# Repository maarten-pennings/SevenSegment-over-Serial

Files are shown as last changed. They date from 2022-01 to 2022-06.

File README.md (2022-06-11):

# Seven Segment over Serial (SSoS)
A device consisting of 7-segment display units, controllable via a serial link (with Arduino sketch and LEGO enclosure).

See a videos of the device in action.

video (https://youtu.be/2fTZVQPiG7E) video (https://www.youtube.com/watch?v=muLhuRukZes)



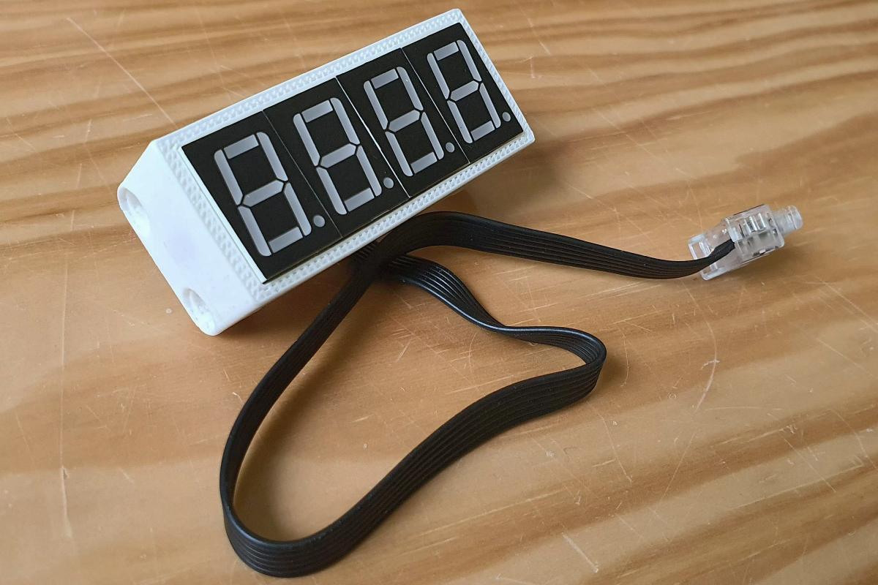
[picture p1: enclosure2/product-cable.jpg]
SSoS for LEGO


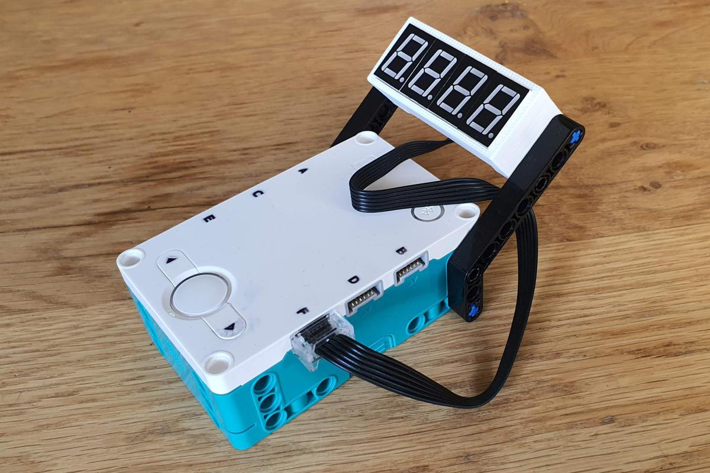
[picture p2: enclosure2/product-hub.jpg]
Connected to the hub


## Introduction
I stumbled on this module [Seven Segment for micro:bit](http://www.monkmakes.com/mb_7_seg.html).
I immediately thought that such a thing would be a nice external display for the new LEGO Mindstorms Robot Inventor - it
does not have a display - at least not one that can display bigger numbers. But I want it smaller to better fit LEGO.

Later I found that [sparkfun](https://learn.sparkfun.com/tutorials/using-the-serial-7-segment-display/all) has something similar.
This board is also a bit too wide to my liking, and _retired_.

## Font
There is a [python script](font) to generate font tables. 
I designed two fonts, one _LookAlike7s_ with characters that are as close as possible to the real thing.
The second font _Unique7s_ maps each character to a unique pattern on the 7-segment display.

## Electronics
Design of the [electronics](electronics): the power architecture, display control, wiring (used pins), schematics, and finally PCB with IDC socket.
My project on EasyEDA is [public](https://oshwlab.com/maartenpennings/ssos).

## ISR model
Modeling the [interrupt service routine (ISR)](isr). The ISR needs to support brightness control and blinking.
The model is made in Python, but in the end, the ISR is the central part of the ATmega firmware, driving the 7-segments.

## Firmware
The [firmware](firmware) for the Arduino Nano, the controller on the SSoS board.
First some proof of concept sketches (using SFRs for ports, timer, ISR), finally the [end-product](firmware/SSoS).

## User manual
There is an extensive [user manual](manual) with examples (as implemented by the [firmware](firmware/SSoS)).

## LEGO enclosure 
I 3D-printed an [enclosure](enclosure) so that I can use SSoS with LEGO Mindstorms.

## LEGO demo
See the [LEGO code](legocode) for some examples of how to use the SSoS device with LEGO.

## Generation 2: Seven Segment over Serial Small
The (LEGO) enclosure we made is 4×8 LEGO units (studs). But LEGO Technic components usually have an _odd_ length.
So I set out to miniaturize making a Seven Segment over Serial _Small_ (SSoSS).
Target is 3×7. To achieve this, I made a single PCB, combining both the "Nano" and the 7-segment units.

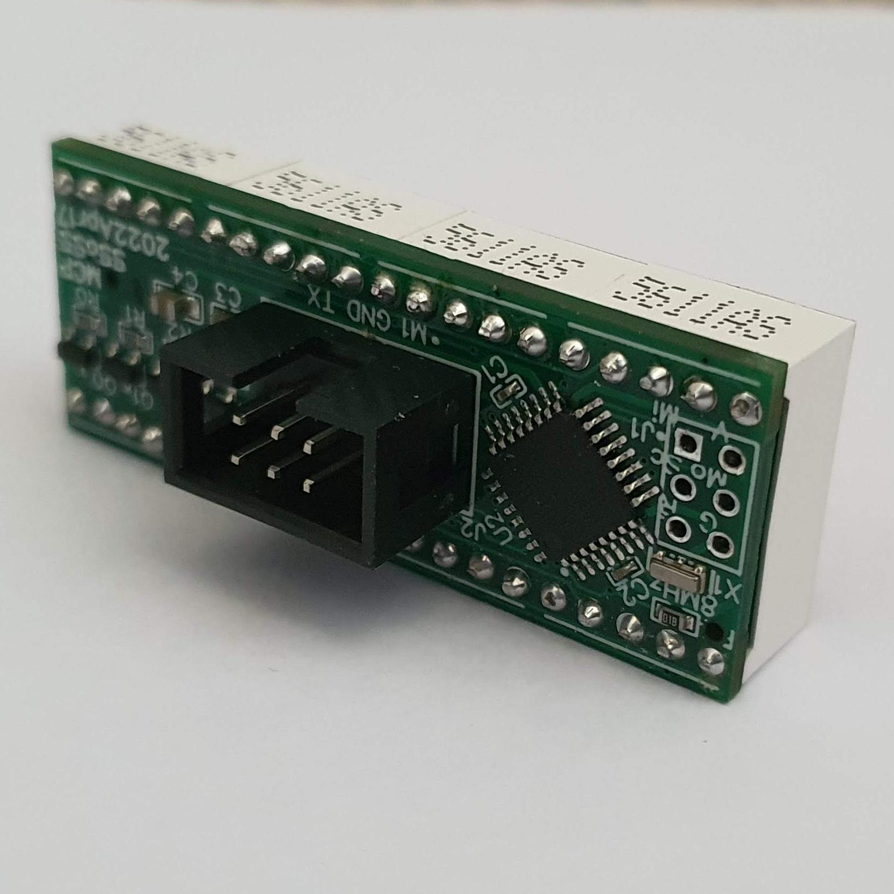
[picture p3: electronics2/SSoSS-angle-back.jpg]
pcb2


Section [electronics2](electronics2) shows the schematics and the unexpected firmware flashing problems.

Section [enclosure2](enclosure2) shows the new enclosure, 3D printed via [JLCPCB](https://jlcpcb.com/DMP).

(end)

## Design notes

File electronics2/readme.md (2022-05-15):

# Electronics - version 2 (small)

Seven-Segment over Serial: a device consisting of four 7-segment display units, 
controllable via a serial link, to be usable as display for LEGO Mindstorms Robot Inventor or Spike Prime.

This page is about the _second_ iteration of the electronics.

The first iteration, depicted below, needed a miniaturization. 

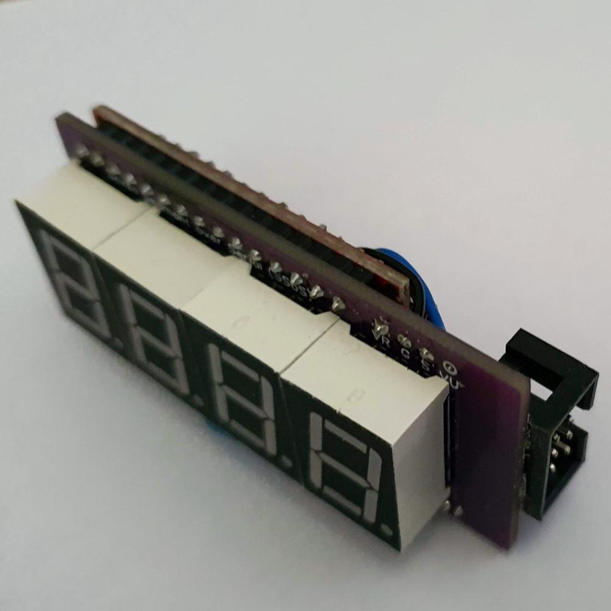
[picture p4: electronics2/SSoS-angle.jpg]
SSoS for LEGO


Miniaturization is achieved by using the SMT service of [JLCPCB](https://jlcpcb.com/DMP).
They sponsored this project.

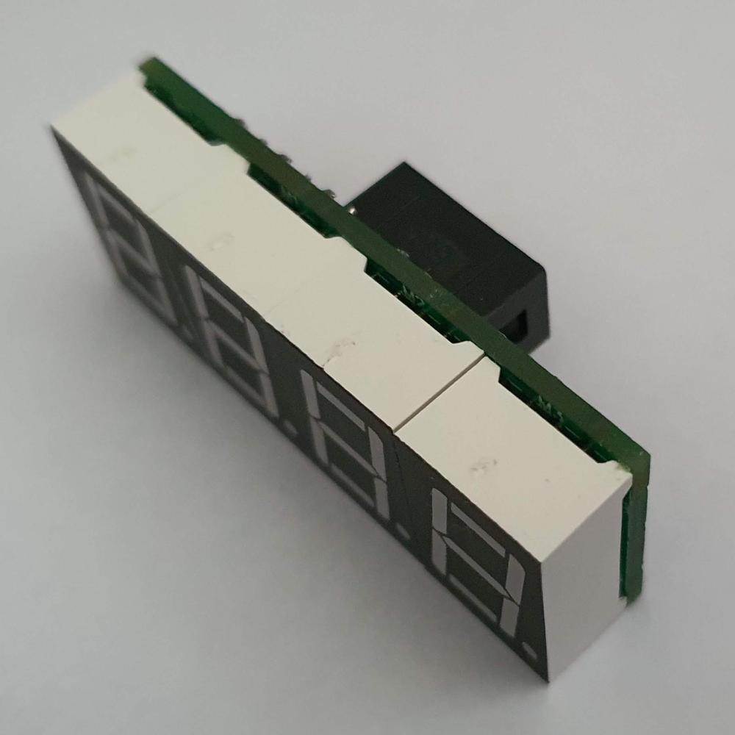
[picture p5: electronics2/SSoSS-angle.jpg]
SSoSS for LEGO


SSoSS for LEGO (backside)

## Introduction

In this miniaturization step I tried to make the design smaller by integrating two boards: "SSoS" and "Nano". 
The "SSoS" board is the board from the [first iteration](../electronics), 
and the "Nano" is a standard Arduino Nano.
The integrated board is nicknamed SSoSS: Seven-Segment over Serial Small.

For firmware, fonts, enclosure, user manual, LEGO code, see parent [page](..).

This article is about switching to SMT components.

## How to get a PCB with components mounted by JLCPCB?

I make all my PCB designs with [EasyEDA](https://easyeda.com/).
Once the design is ready, I let EasyEDA export a Gerber, and I send that to [JLCPCB](https://jlcpcb.com/DMP) to get it manufactured.
There is a third company in the mix, [LCSC](https://lcsc.com/); this is a component supplier.

### EasyEDA - select components

Design the schematics as usual.
For each component you add to the schematics you have to make a choice
 - JLCPCB can't mount it because JLCPCB can only mount on one side of the board and this component needs to be on the other side.
 - JLCPCB can't mount it because its supplier, LCSC, doesn't have the component on stock.
 - You tell JLCPCB not to mount it because it is only needed for testing, or you have plenty stock yourself, or its is cheaper.
 - ... You want it mounted.

In the latter case be sure to select a component from LCSC, because that is the supplier of JLCPCB.
There are three classes of components
 - JLCPCB can not deliver it (not in LCSC catalog or the LCSC stock is depleted).
 - The component is a so-called _Extended Part_. 
   This means that JLCPCB has it, but it is not in the parts feeder by default.
   An operator needs to change the feeder on the pick-and-place machine, 
   you have to pay ~$3 per extended component class (plus the normal per-component cost).
 - It is a so-called _Basic Part_. 
   This means that JLCPCB has it in the feeders of the pick-and-place machines.
   You only pay the per-component cost.

There are two ways to find a component: 
you can do that in EasyEDA designer or on JLCPCB website.

### Finding a component in EasyEDA

Finding a component in the EasyEDA design tool.
 - Open the `Library` tool in the designer.
 - Enter a search term, e.g. `220 0805` for a 220 ohm resistor in size 0805.
 - Search in `Class` LCSC.
 - Sort on `JLCPCB Part Class` so that we can check if there is a _Basic Part_ (they are cheaper after all).
 - Click the wanted component and check _Stock_ at the bottom of the screen (example below: 182000 pieces).
 - An important number is the _LCSC Part#_, also at the bottom line.
   See the example in below screenshot, finding component `C17557`.
 
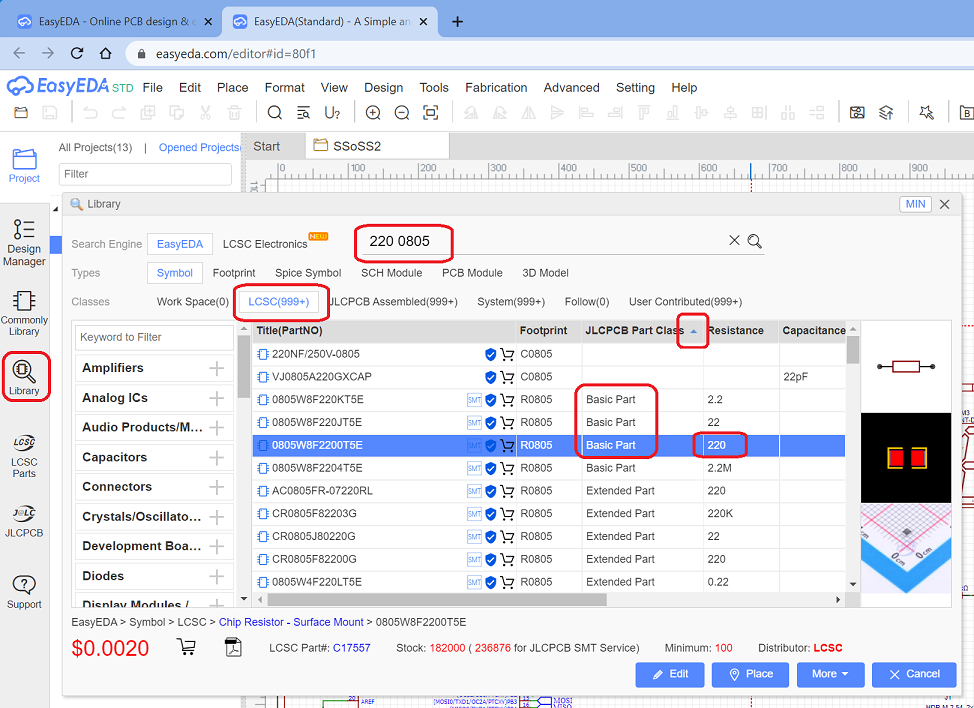
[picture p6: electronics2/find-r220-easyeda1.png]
EasyEDA find component
   

### Finding a component in JLCPCB

Finding a component in the EasyEDA design tool works OK.
But somehow, I find it easier to search for parts on the JLCPCB website.

 - In the main page select `Resources` then `SMT Parts Library`.
 
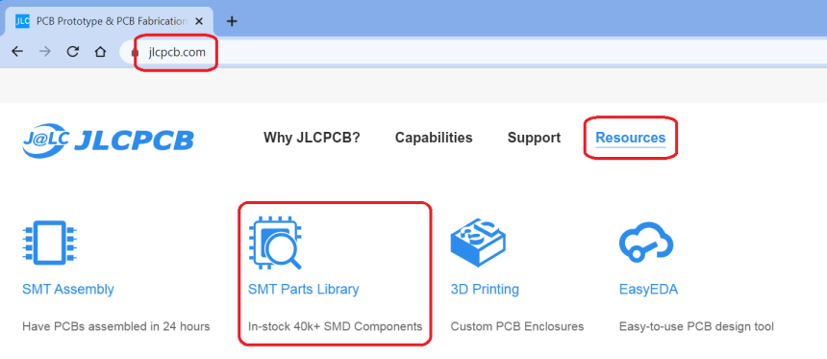
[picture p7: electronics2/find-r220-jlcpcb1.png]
JLCPCB find page
   
   
 - You can search by category (resistors, transistors, diodes), and/or using filters, or simple keyword search.
   For example if you search for `220Ω 0805` (ALT-235 gives the Ω in windows) and place a check mark for _Basic Parts_
   we find the same component as before.
   
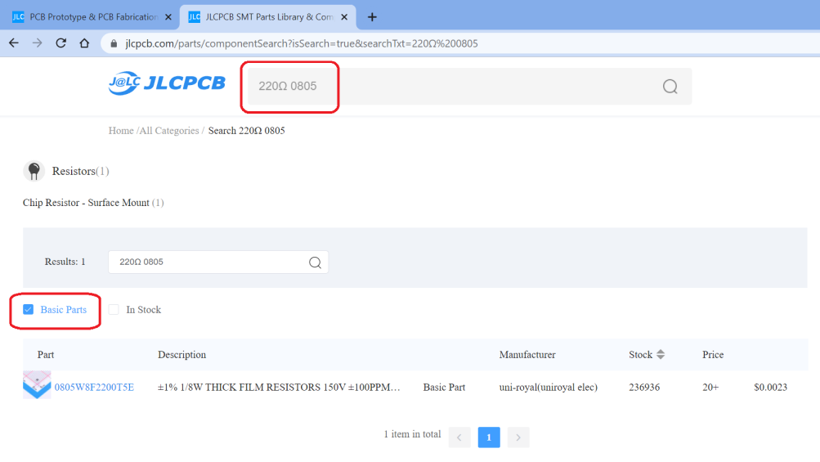
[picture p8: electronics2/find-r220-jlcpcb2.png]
JLCPCB find search
   
   
 - Click the component for to fold open its details
 
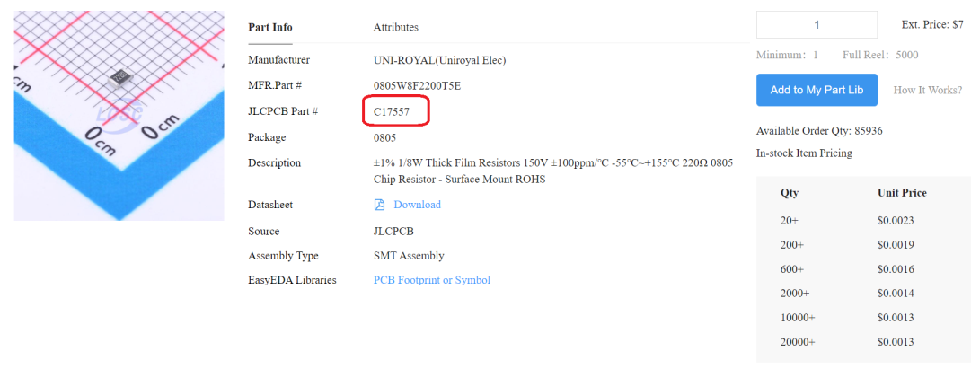
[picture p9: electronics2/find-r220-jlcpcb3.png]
JLCPCB find page
   
   
   Note that we have the same part number as when searching via EasyEDA.
   
 - Just enter that number in the Library search box of Easy EDA.
 
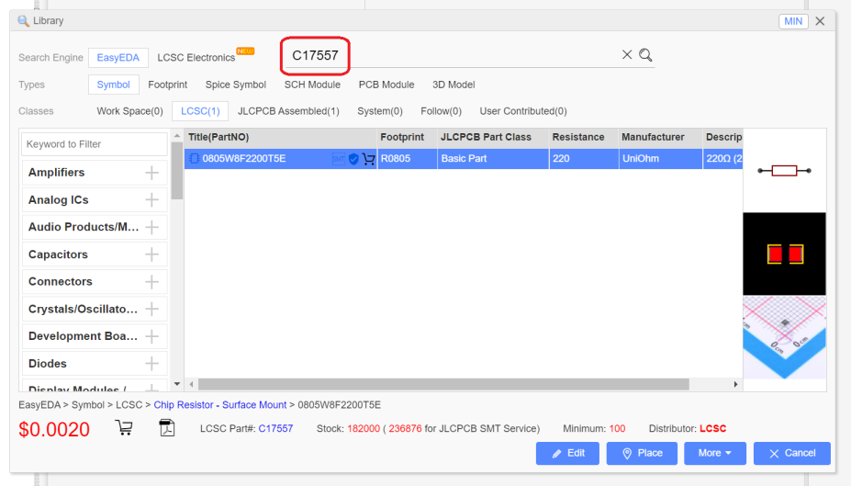
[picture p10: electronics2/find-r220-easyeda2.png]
EasyEDA find component
   

### EasyEDA - design PCB

After picking all SMD components, this is the resulting [schematic](Schematic_SSoSS.pdf).
You can't see it from the schematics (but you can see it in the EasyEDA designer), 
but all SMD components can be sourced from LCSC.

Once the schematics is drawn with the JLCPCB supported components, proceed to the PCB layout stage as usual.
No special attention here, other then to draw the components you want mounted all on the same side.

In my case, this is the resulting PCB, [front](front-3D.png) and [back](back-3D.png) view.
The back side will not be mounted by JLCPCB, so I took big 0805 components that I will mount myself.

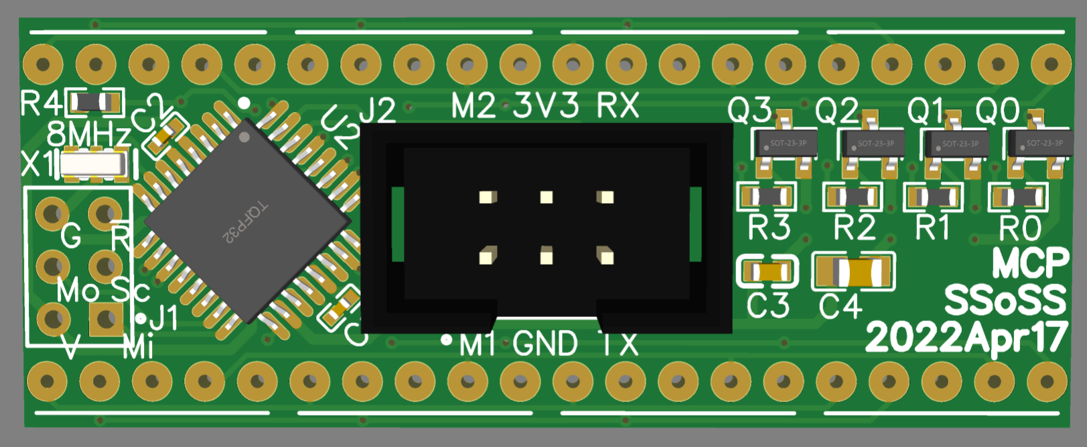
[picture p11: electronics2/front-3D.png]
front


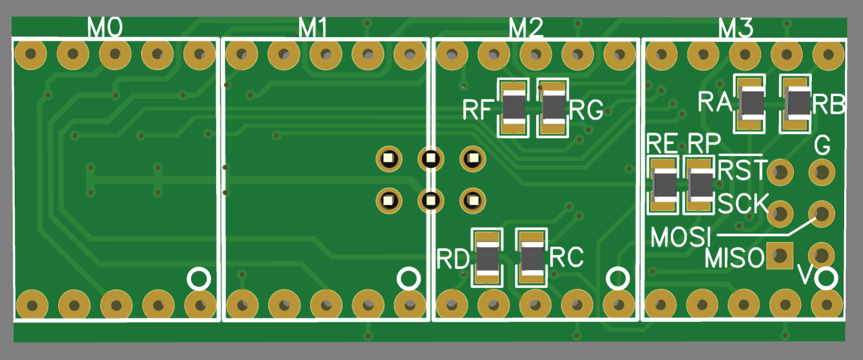
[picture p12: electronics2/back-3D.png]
back


An extra step is needed when exporting the project. In addition to the _Gerber_ file, 
JLCPCB needs a _bill of material_ (BOM) and _pick-and-place_ instructions.
You find the other two exports also in the `File` menu, above and below the Gerber exporter.

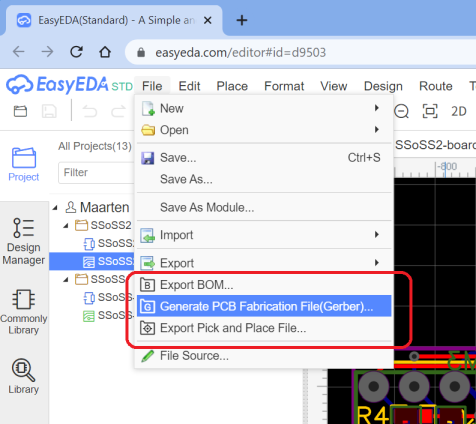
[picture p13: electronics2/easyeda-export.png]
export


For my project, all exported files are in the [order2](order2) directory.

### JLCPCB - import

We visit the [JLCPCB](https://jlcpcb.com/DMP) website to prepare our order.

 - Go to the PCB quote form.

 - Drag in the Gerber file we just exported. As usual we get a preview.
   We leave all parameters to standard. 
   Cost are very low: $2 for the special offer (5 small PCBs), plus nearly $4 for lowest shipping.

 - The first step is to enable component mounting at the bottom of the form.

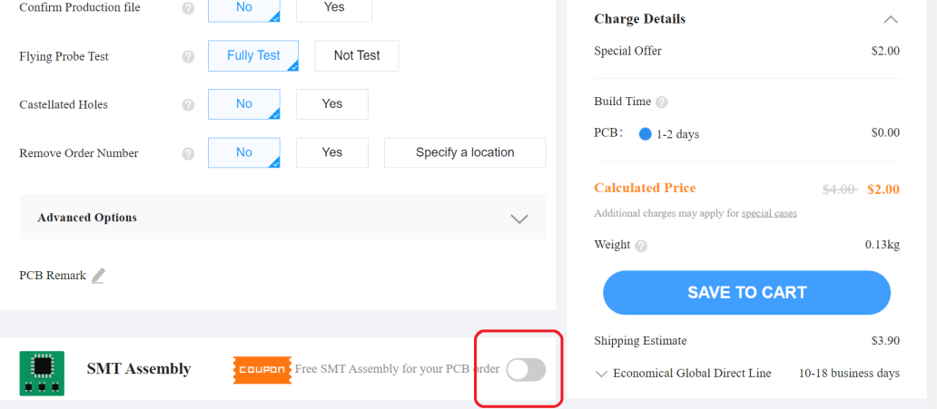
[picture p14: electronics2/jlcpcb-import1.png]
enable component mounting
   

 - The pricing changes. You now have to pay $8 general setup cost and $1.50 to make a stencil
   (a metal sheet with holes matching the component pads, this is used to apply the soldering paste at the correct spots).
   So total cost is now $2+$8+$1.50 or $11.50 plus shipping (still $4).

 - The quote form also expands: we have to chose which side will be populated with components, 
   and how many of the PCBs we want to be assembled. 
   Bit strange: we can only chose all 5 or just 2, but 2 is fine for me.

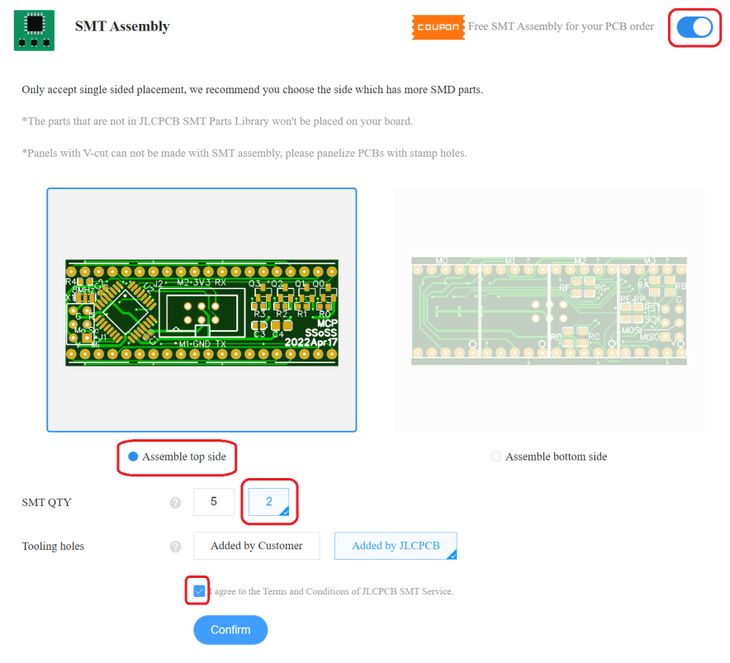
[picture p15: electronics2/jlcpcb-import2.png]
side and quantity
   

 - Once that is confirmed, we get a dialog, where we need to upload the _BOM file_ 
   and the _pick-and-place file_ we exported earlier. 
   Also you need to fill out the kind of project your are making, I selected `Electronics and Hobbies - DIY`.

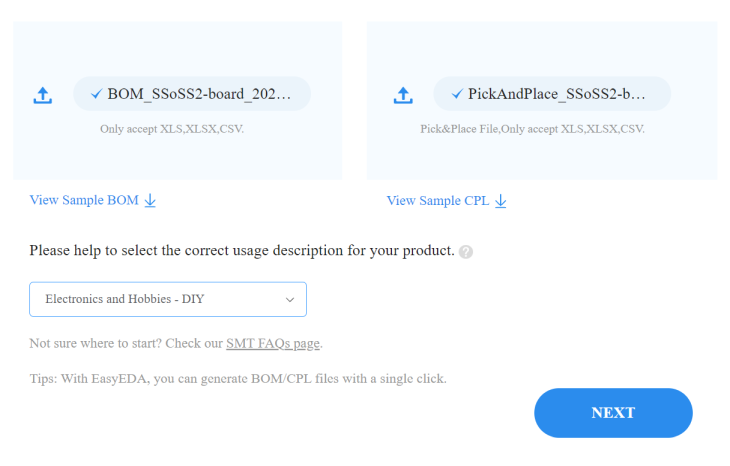
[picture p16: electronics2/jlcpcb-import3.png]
BOM and pick-and-place
   
 
 - Once the BOM and pick-and-place files are uploaded, we get a new form for part selection.
   Here we can see if there are problems with components (you selected one whose stock ran out - yes I had that!).
   More importantly, you can deselect components. For example, I do not want J1 and J2 to be mounted.
   I was surprised to see them enabled, because they are not SMT components, 
   but apparently JLCPCB has an optional hand mounting post processing step - nice!

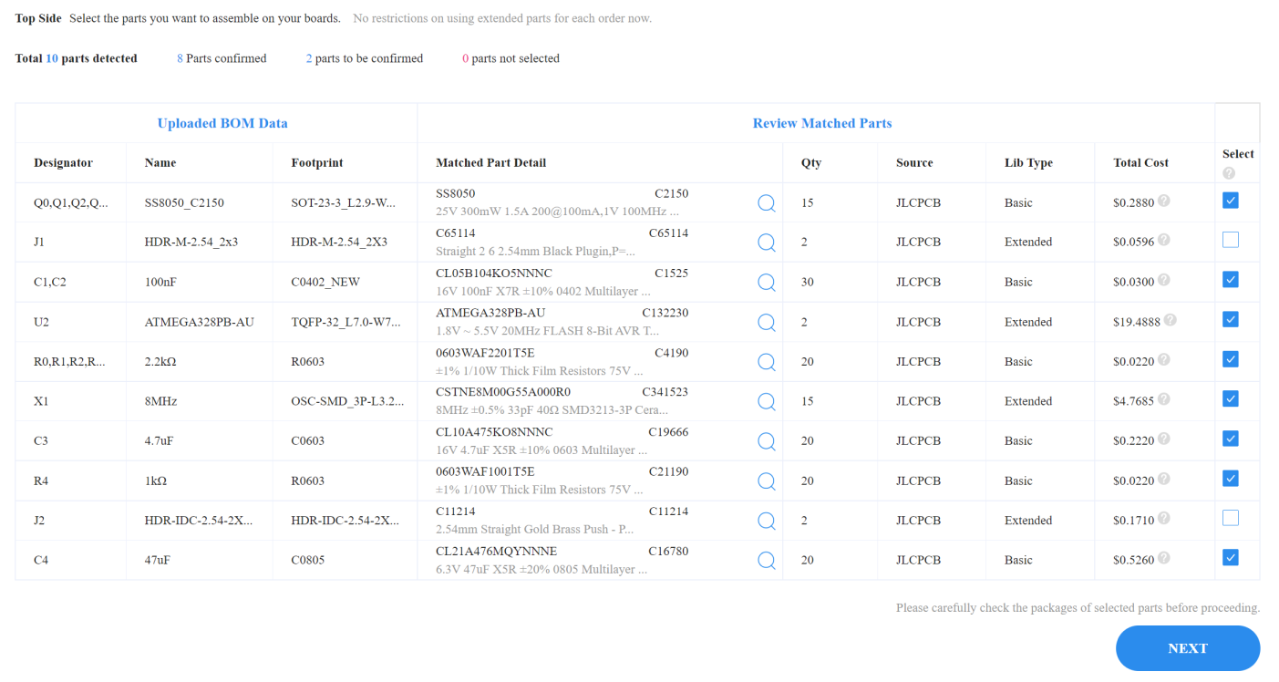
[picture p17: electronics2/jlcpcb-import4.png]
component deselect
   

   The Qty column confused me at first. It does _not_ show actual quantity, 
   but what "rank" your order is in (e.g. 1-19, 20-199, 200-599, 600-2999), because that determines the price.
   When you need low quantities (as I do) you are in the first rank. 
   That rank is a bit special: the price is fixed irrespective of quantity; 
   if you fold the line item open it reads e.g. `*For qty≤20, charges a fixed fee of €0.0203`.

   If you select an extended component, JLCPCB is required to change the feeders on the pick-and-place machines,
   which requires an additional labor fee, $3 per Extended Component type.

 - After clicking next, we are back at the main form.
 
   We see which components are placed (basically a copy of the previous  list), but also
   which components are not. In my case that is the two deselected headers and the components
   on the back side. A nice cross-check.
   
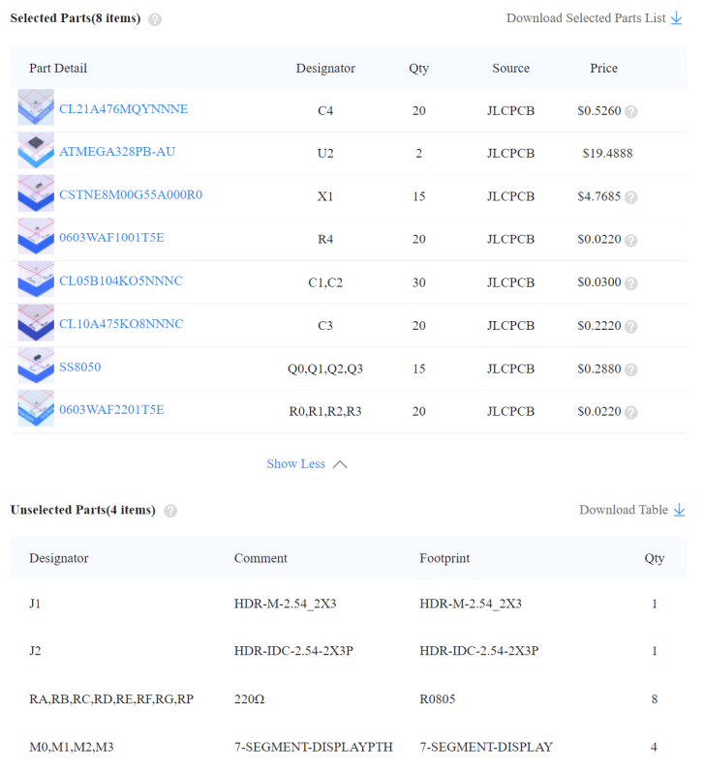
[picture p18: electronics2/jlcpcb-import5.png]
   
   
   Note that passives (resistors, capacitors) are typically very low priced 
   (although for these small quantities we are in lowest rank and pay the relatively high fixed price).
   The ATmega328 is unbelievably high priced. An Arduino Nano board with that ATmega328 goes for $2 on AliExpress.
   I guess I pay for the semiconductors shortage (April 2022).
   
   Also the oscillator is expensive. On top of that, the ATMEGA and oscillator are extended components so
   we need to pay an extra $3 for both.
   
 - Pricing has gone up: we have to pay for all components, we have to pay for changing the feeders 
   (2 extended components so $6 in total), and we have to pay for the solder 
   (JLCPCB states $0.0017 per solder joint but that would be nearly 400 joints).

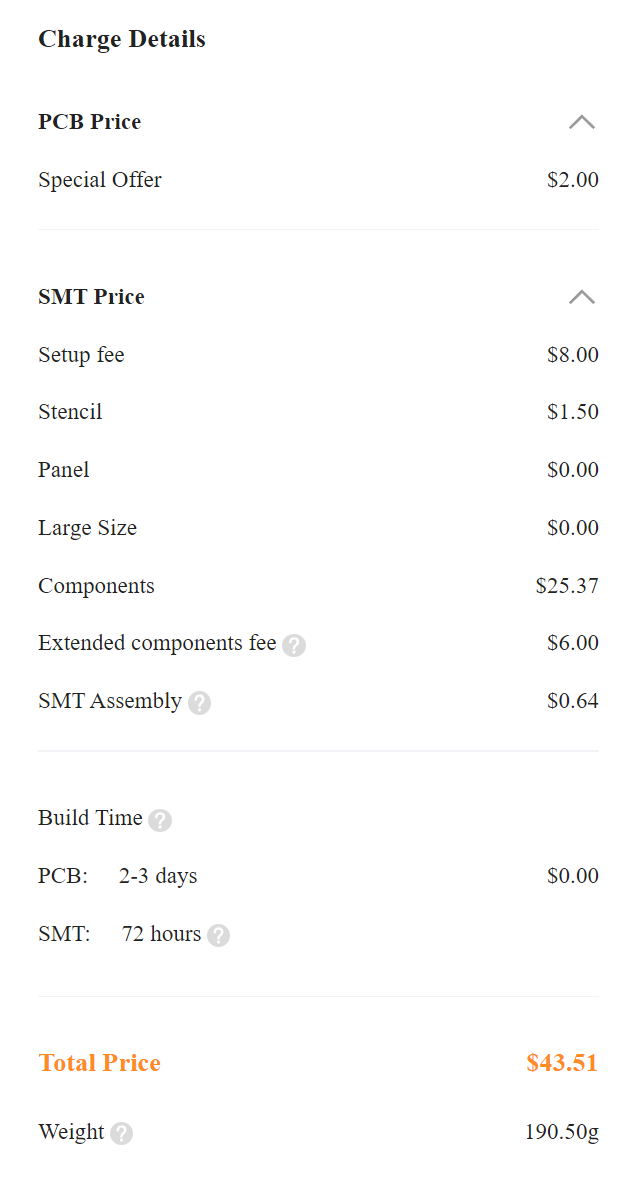
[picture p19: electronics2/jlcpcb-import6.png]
   
   
 - When I put this in my cart and paid, there was an unpleasant surprise.
   Suddenly I had to pay $12 tax. That had never happened before.
   And shipping increased to $8. Is that the extra weight?
   Feels a bit excessive. 
   
   I also stumbled on another problem: I had multiple gift cards (vouchers) but could only hand in one.

## Considerations and doubts on the tech side

Considerations before producing the board:
 - I used the ATmega328, not the ATM168 from SSoS, LCSC doesn't have the 168.
 - The ATmega328 on LCSC is very expensive ($10), so I only make two boards.
 - I'm a digital (software) guy, so I have doubts in the analogue domain
   - Do I have the correct oscillator (I need 8MHz for ATmega328 at 3V3) - correct capacitance?
   - Are the transistors correct?
   - There is no cap on the RESET# pin.
   - No ground poor.
 - I will solder J2 (IDC connector) myself, and J1 (ICSP) will not be mounted.
 - I will solder RA..RP myself (JLCPCB can only do one side), they are 0805.
 - I did make my own 3D model of the [IDC connector](IDC3dModel).

Considerations after producing the board:
 - One LED on the PCB might have been nice for testing bring-up.
 - A pad for PORTB0 would have helped in clock testing (see CKOUT fuse bit).
 - The ATmega328PB that I took is not nicely supported by Arduino. It works, but an ATmega328P would have been easier.

## Flashing

The board is back, from 2022-04-17 to 2022-04-23 for production and mounting (5 days) to 2022-05-04.
In total 18 days for manufacturing and shipping. 

There was one thing to caught me by surprise: the board had two holes I did not put there,
see the red encircled areas. I guess those are put by JLCPCB to have anchor points 
for the solder paste stencil.

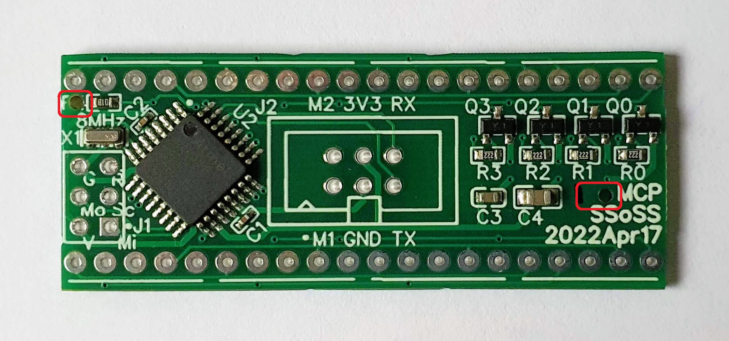
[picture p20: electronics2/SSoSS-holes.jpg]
SSoSS

 
The [flashing](flashing) took two days of trial and error, reason was I have the ATmega328PB, not standard ATmega328P.
This means fiddling with fuses, avrdude, and fixing a bug in the driver (hardcoded 16MHz clock).

## Assembly

Once the firmware was correctly working and flashed, and I could proceed with final assembly.
The components "brace" each other, so once assembled, there is little opportunity for changes.

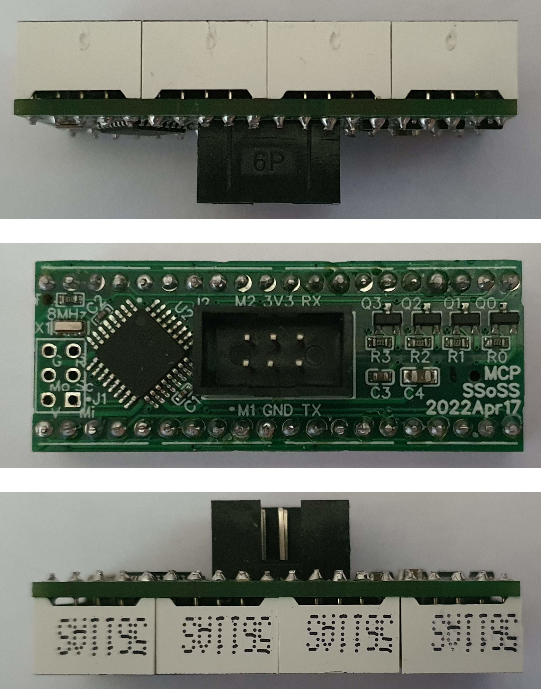
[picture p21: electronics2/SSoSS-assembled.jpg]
SSoSS assembled


## Enclosure

What is left is to make a new [LEGO enclosure](../enclosure2) for this smaller PCB.

(end)

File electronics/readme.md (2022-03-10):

# Electronics

Seven-Segment over Serial (SSoS) module: a device consisting of four 7-segment display units, 
controllable via a serial link, to be usable as display for LEGO Mindstorms Robot Inventor or Spike Prime.

This section is about the electronics of the SSoS board, 
design made with [EasyEDA](https://easyeda.com/) and manufactured by [JLCPCB](https://jlcpcb.com/DMP).

For firmware, fonts, enclosure, user manual, LEGO code, see parent [page](..).

This article was awarded a $50 voucher from [JLCPCB](https://jlcpcb.com/DMP).

## Arduino Nano power architecture

The heart of SSoS module is an Arduino Nano. 
We need to power it from a LEGO hub port, which is 3V3.
Is that possible? 

The diagram below is a high level view of the 
[schematics](https://www.arduino.cc/en/uploads/Main/ArduinoNano30Schematic.pdf) 
of a Nano, focusing on power.

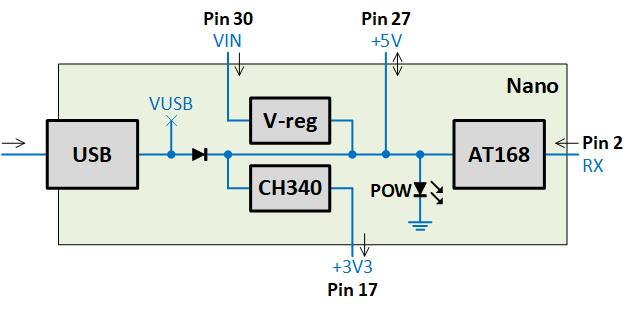
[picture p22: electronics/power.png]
Arduino Nano power architecture


A Nano can be powered via
 - the `USB` connector;
 - 6 to 20V _unregulated_ external power supply (pin 30, `VIN`) - it is regulated internally (by V-reg); 
 - 5V _regulated_ external power supply (pin 27, `+5V`).

Note that
 - the `+3V3` (pin 17) is a low-current output supplied by the CH340;
 - the `+5V` (pin 27) can be used as output, provided the Nano is powered via `USB` or `VIN`;
 - `VUSB` is not pinned out;
 - the "power" LED is connected to the internal 5V rail;
 - a diode protects a USB host in case the Nano is inadvertently connected via `USB` and `VIN`/`+5V`;
 - according to the datasheet the operating voltage is 2.7V-5.5V for Atmel ATmega48/88/168.
 - this means that we can use pin 27 `+5V` also as input, provided we attach a _regulated_ power in the range 2.7V-5.5V.

**Conclusion**
We power the board by connecting pin 27 (`+5V`) to the external host (LEGO hub).
This is fine as long as the external host a "standard" regulated voltage (e.g. 3V3 or 5V). 
It also means that the logic pins, e.g. the incoming `RX` will have the host level.

## Display control

How does the Nano control the four seven-segment units?

According to the ATmega48/88/168 datasheet:
 - each I/O port can **source** more than the test conditions (20mA at VCC = 5V, **10mA** at VCC = 3V)
 - the sum of all IOH, for ports C0 - C5, D0- D4, ADC7, RESET should not exceed 150mA.
 - the sum of all IOH, for ports B0 - B5, D5 - D7, ADC6, XTAL1, XTAL2 should not exceed 150mA.

Similarly,
 - each I/O port can **sink** more than the test conditions (20mA at VCC = 5V, **10mA** at VCC = 3V)
 - the sum of all IOL, for ports C0 - C5, ADC7, ADC6 should not exceed 100mA.
 - the sum of all IOL, for ports B0 - B5, D5 - D7, XTAL1, XTAL2 should not exceed 100mA.
 - the sum of all IOL, for ports D0 - D4, RESET should not exceed 100mA.

So, sourcing 8 LEDs via 8 output pins is fine, as long as each LED gets 10mA max.

Sinking 8 LEDs via 1 output port is **not** ok, that would be 80mA where the max is 10mA.

**Conclusion**
We connect the four seven-segment displays in a row/column fashion. 
The individual segments ("rows") can be hooked directly to an output pin of the ATmega, provided that the current limiting resistor limits the LED current and thus the sourcing via the pin to 10mA.
The commons of the display ("columns"), need to sink, worst case, all 8 LED segments of a display unit. As a result, we use a transistor.
The principle is depicted below, for the real schematic see section below.

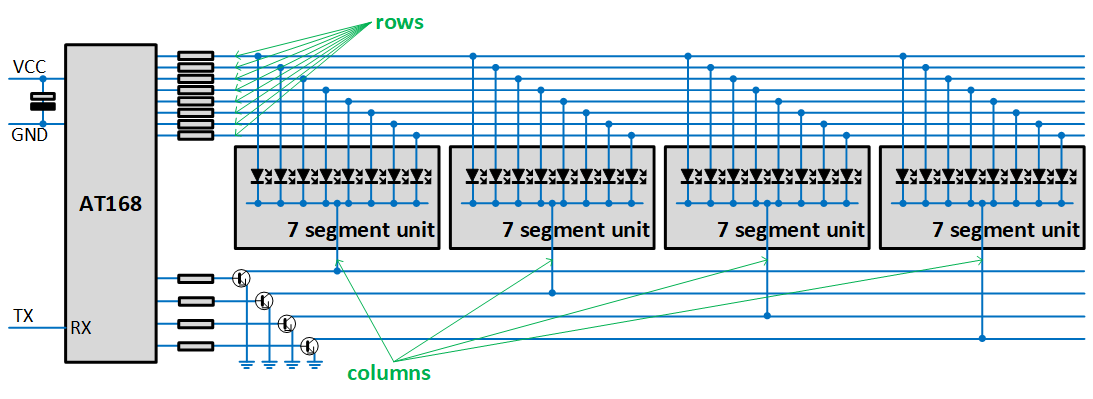
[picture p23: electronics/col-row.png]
Display control


I decided to have current limiting resistors of 220 ohm for the LEDs.
Red LEDs have a forward voltage of Vf=1.8. 
With an external voltage of 3V3, the resistor drops 1.5V (3.3-1.8), leading to a current of 6.8mA for one segment and 55mA for all 8.
With an external voltage of 5V0, the resistor drops 3.2V, leading to a current of 14.5mA for one segment and 116mA for all 8.

| VCC | V_R (V)| I_R (mA) R=220Ω | I_common (mA) 8 LEDs |
|----:|---:|---:|---:|
| 3.3 | 1.5 | 6.8 | 55 |
| 5.0 | 3.2 | 14.5 | 116 |

I'm not completely sure about the dimension of the base resistor.

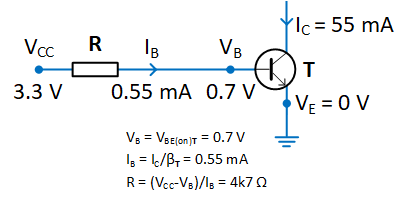
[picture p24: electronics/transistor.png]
Transistor


If we assume I_C to be 55mA, and the gain (hFE, beta?) to be 100, then I_B is only 55mA/100 or 0.55mA.
There is a voltage drop across BE in the transistor, which is typically V_BE=0.7V. The emitter is grounded so V_B=0.7V.
The Arduino GPIO pin outputs VCC=3.3V, so we need a voltage drop over the base resistor from 3.3V to 0.7V or 2.6V.
With Ohm's law we find R = V_R/I_R = 2.6 / 0.55m = 4k7Ω.

| VCC | I_C (mA) | I_B (mA) β=100 | V_R (V) VCC-V_B | R (Ω) V_R/I_B) |
|----:|---:|---:|---:|---:|
| 3.3 | 55 | 0.55 | 2.6  | 4727 |
| 5.0 | 116 | 1.16 | 4.3  | 3706 |

So, 2k2 seems save to make sure the transistor is saturated...

## Wiring

We will use the pins as marked in the dark blue bars. 
Note that we have 6+6 row/column pins, which will be used to drive 8 columns and 4 rows.
We tried to group these in so-called ports so that a single SFR assignment suffices.

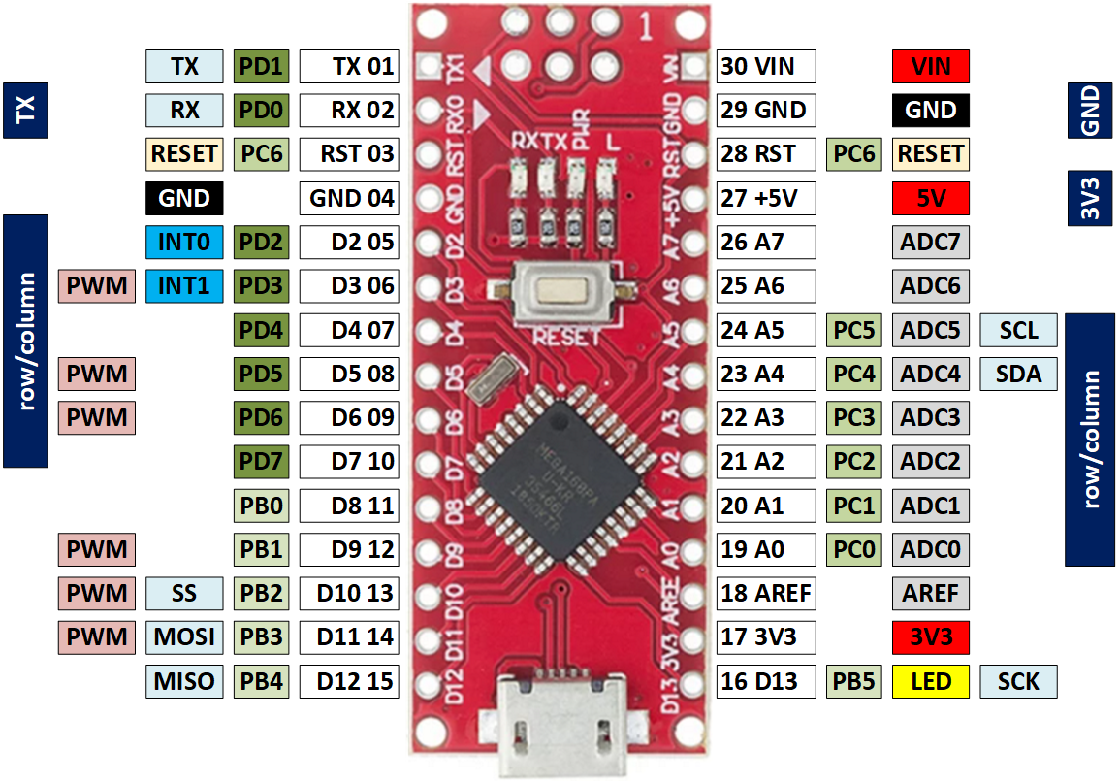
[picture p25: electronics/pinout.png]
Wiring


The breadboard prototype works, but the LEGO mindstorms 3V3 is on the edge.

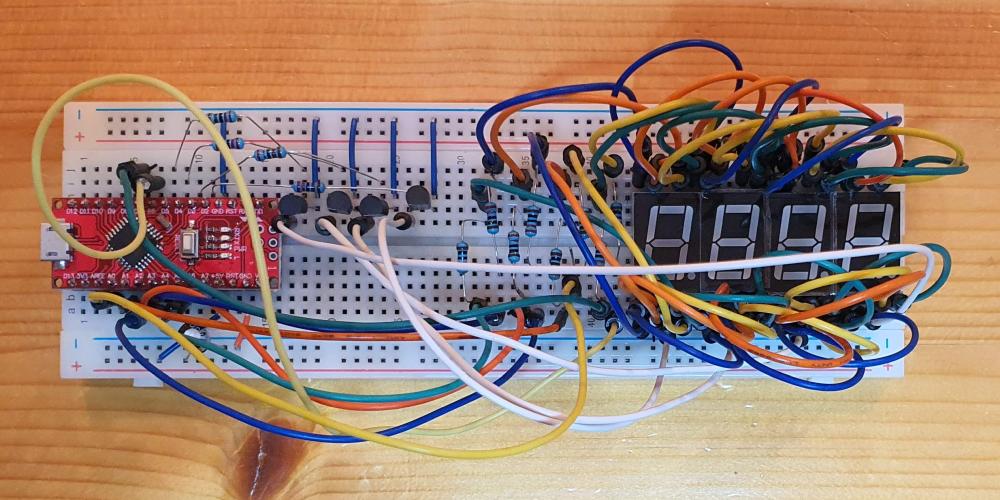
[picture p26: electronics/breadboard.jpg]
Breadboard


## PCB production

I used [EasyEDA](https://easyeda.com) to design a PCB.
My project is [public](https://oshwlab.com/maartenpennings/ssos).
First step was to make [schematics](Schematic_SSoS.pdf).

I intend to use SSoS for LEGO Mindstorms.
The output voltage is a bit low, so I decided to reserve room for an optional [boost converter](https://www.aliexpress.com/item/32762622485.html).
The host always connects to J1.
 - Host has regulated power in the range of 3-6V: 
   connect **VR**egulated, **G**round, **S**erial of J1.
 - Otherwise mount buck or boost regulator on J2 and 
   connect **G**round, **S**erial, **VU**nregulated of J1

Next comes layout in [EasyEDA](https://easyeda.com).
I wanted a small board, so used SMDs for the resistors, and populated the board on both sides.

Note that soldering will be a bit tricky: the Nano and seven-segment hold each other in a "brace".
Here the renders of the top and bottom of the PCB.

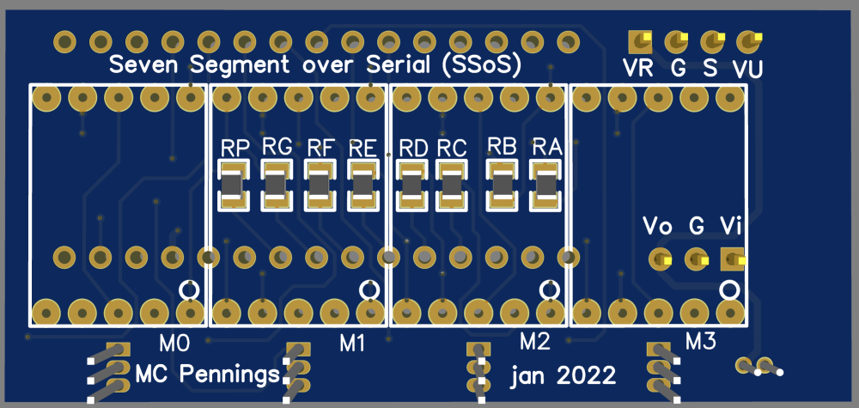
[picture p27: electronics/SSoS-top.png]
PCB rendered top


PCB rendered bottom

The final step is to generate the [gerber](Gerber_SSoS.zip) file.
I sent those to [JLCPCB](https://jlcpcb.com/DMP).
For small quantities JLCBCP is great value for money: 
five PCBs for €1.77 plus €3.84 shipping (3 weeks to Europe).

This is what came back - I tried the new PCB color purple :-)

PCB actual top

PCB actual bottom

The result after mounting the components (you can't even see the SMDs anymore).

Module actual top

Module actual bottom

Possible improvements:

- I should have rotated the Nano board (USB connector on the outside).
- I should have made better provisions for the IDC connector towards the LEGO Mindstorms hub.
- I maybe should have spaced the transistors to match holes for LEGO Technic pins.
- This design is now 8×4×2 studs, which does not match LEGO's philosophy of having an odd number of studs in the Technic world.

## IDC connector

I always confuse myself with the pin-out of the connectors: male and female, front and back view.

This is the LEGO hub pinout.

hub pinout

I have one LEGO (power functions 2, powered up, spike prime, robot inventor, control +) 
to IDC cable, I use [2×3 6P](https://www.aliexpress.com/item/4001257530318.html).

IDC cable

Here is an example of matching [2×3 6P](https://www.aliexpress.com/item/1005001400147026.html) socket.
The SSoS module needs this wiring on the IDC socket. 

IDC pinout

This is the PCB end-result - with the socket glued...

Module actual bottom

## Final product

Elsewhere in the [project](..), you find the firmware for the Nano, and the STL for the LEGO case.
This is how the encased PCB-with-cable looks like.

encased

Here the SSoS module is in [action](https://youtu.be/2fTZVQPiG7E) in a simple robot.

motor

## References 

 - [This project](https://oshwlab.com/maartenpennings/ssos)
 - [Arduino Nano description](https://www.arduino.cc/en/pmwiki.php?n=Main/ArduinoBoardNano)
 - [Arduino Nano schematics](https://www.arduino.cc/en/uploads/Main/ArduinoNano30Schematic.pdf)
 - [ATmega168 information (and datasheet)](https://www.microchip.com/en-us/product/ATmega168)
 - [LEGO connector on Philo's site](https://www.philohome.com/wedo2reverse/connect.htm)
 - [EasyEDA](https://easyeda.com)
 - [JLCPCB](https://jlcpcb.com/DMP)
 - [AliExpress](https://www.aliexpress.com/)
    - [Nano](https://www.aliexpress.com/item/32969876875.html)
    - [LEGO cable](https://www.aliexpress.com/item/32871195908.html)
    - [7 segment common cathode](https://www.aliexpress.com/item/33058771440.html)
    - [IDC plug 2×3 6P](https://www.aliexpress.com/item/4001257530318.html)
    - [IDC socket 2×3 6P](https://www.aliexpress.com/item/1005001400147026.html)
    - [SMD resistors](https://www.aliexpress.com/item/32865947306.html)
    - [Capacitor](https://www.aliexpress.com/item/1005002842732971.html)
    - [Transistor](https://www.aliexpress.com/item/1005003363864621.html)

(end)

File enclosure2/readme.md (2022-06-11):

# Enclosure version 2 (small)

I made an enclosure (case) for the _Seven-Segment over Serial Small_ device.

I designed the enclosure in [Fusion 360](https://www.autodesk.eu/products/fusion-360), 
and printed it on my [Cetus3D](https://shop.tiertime.com/product/cetus-3d-printer-mk3/).

I made one key design decision: the PCB has a friction-fit in the enclosure. 
That is the plan: no screw, no glue, maybe a bit of click.

[JLCPCB](https://jlcpcb.com/DMP) offered me to try their 3D-printing services, which is gladly accepted.

## Designing the new enclosure

Goal is to design an enclosure matching LEGO Technic dimensions: a 7×3×3 (LEGO) studs.

### Modeling

I started by modeling the PCB with some key components (the 4 7-segment units, the IDC socket, and the ATmega328).

PCB top

PCB bottom

Here is the PCB, but now in its enclosure. The width and height are 3 by 7 LEGO "units" (studs). 
At the back some "wings" for mounting to Technic pieces.

Product top

Product bottom

This is the enclosure in isolation. At the back the hole for the IDC socket, on the inside the ridges where the PCB rests 
and a gutter (hardly visible) above the ridges to click the PCB in place.

Enclosure top

Enclosure bottom

The final figures show a sectional view on the short and long side. 
The short sectional view shows the gutter for the PCB more clearly.

Section short

Section Long

### STL files

Here is the STL file for the enclosure.
It is a single [stl file](enclosure.stl)
Print on my Cetus3D (0.15mm layer height, 13% infill, fine quality, with support and raft)
was estimated at 1.9h and 15.0g of PLA.

### 3D print results on Cetus3D

enclosure 1

enclosure 2

enclosure 3

enclosure 4

### Electronics enclosed

The fit is tight. It was hard to get the PCB in, no risk of it dropping out, but also hard to get out.

product 1

product 2

product 3

product 4

Finally, with cable and hub.

product with cable

product with hub

## 3D print via JLCPCB

[JLCPCB](https://jlcpcb.com/DMP) offers various 3D printing technologies: SLA, MJF, SLM, and FDA.

### Technologies

- **SLA (resin)**  
  SLA or Stereolithography is an additive manufacturing process that belongs to the vat photopolymerization family. 
  The vat (tub, container) contains a photo sensitive (liquid) resin. A light source (e.g. laser) is used to cure (solidify) the resin 
  ([youtube](https://www.youtube.com/watch?v=TuubPMWeQQE&t=143s)).
  This method is popular because it produces high-accuracy parts with fine features and smooth surface.
  
  JLCPCB offers 3 resins: LEDO 6060, 9000R and 8000. They are all white.
  Also the lowest cost, my model is $1.
  
  JLCPCB SLA
  
- **MJF (Nylon)**  
  MJF or Multi Jet Fusion is an industrial 3D printing process that quickly produces nylon parts.
  It uses an inkjet array to apply (fusing and detailing) "ink" across a bed of nylon powder, which are then fused with heat. 
  The [process](https://xometry.eu/en/multi-jet-fusion-mjf-3d-printing-technology-overview/) repeats layer after layer ([youtube](https://www.youtube.com/watch?v=KKyQJLe_G6o)).
  
  JLCPCB offers 2 nylons: PA12-HP (black or gray) or PAC-HP (multicolor).
  The PA12-HP is still affordable ($3.64 for my model), but PAC-HP gets expensive ($23.64)
  
  JLCPCB MJF

- **SLM (metal)**  
  SLM or Selective Laser Melting (aka DMLM or direct metal laser melting), is a method for a metal additive manufacturing technology.
  It uses a bed of powder with a heat source to create metal parts ([youtube](https://www.youtube.com/watch?v=yiUUZxp7bLQ))
  
  JLCPCB offers 1 material: 316L stainless steel. Higher price range: $23.56 for my model.
  
  JLCPCB SLM
  
- **FDM (ABS)**  
  FDM or Fused Deposition Modeling (or Fused Filament Fabrication) is the offical name for the well-known process used in hobby printers.
  It works by depositing melted filament material (plastic wire from a spool) over a build platform 
  layer by layer until you have a completed part ([youtube](https://www.youtube.com/watch?v=raSAhXb2ea4)).
  
  JLCPCB offers 1 material: ABS in white and black. Moderate price point: $3.83.

  JLCPCB FDM

### Summary offers JLCPCB

| abbr | full name | material | price($) |
|:-----|:---|:---|---:|
| SLA  | Stereolithography | LEFO6060 | 1.00  |
| MJF  | Multi Jet Fusion | PA12-HP Nylon | 3.64  |
| SLM  | Selective Laser Melting | stainless steel | 23.56  |
| FDM  | Fused Deposition Modeling | ABS | 3.83  |

### Ordering

[JLCPCB](https://jlcpcb.com/DMP) offered me to try their 3D-printing services, so I tried the three low-cost versions: SLA, MJF nylon, and FDM.
After submitting my model, JLCPCB does a (presumably) automated _design rule check_ for manufacturability. 
And my designs came out negative :-(

> The wall thickness like those red area are too thin which has a high risk of crack, loss and deformation.

JLCPCB assessment

> SLA LEDO 6060 Resin:  
> Will this risk be acceptable for you? If not, could you please kindly increase it to be at least **0.8mm** to proceed? 1.5mm will be better.

> MJF PA12-HP Nylon:  
> Will this risk be acceptable for you? If not, could you please kindly increase it to be at least **1.0mm** to proceed? 2.0mm will be better.

> FDM ABS White:  
> Will this risk be acceptable for you? If not, could you please kindly increase it to be at least **1.2mm** to proceed? 2.0mm will be better.

I answered that these are LEGO Technic dimensions, so I can not really change them.
That I printed the object on my own Cetus3D, and that worked.
My last argument was that this is a trial anyhow to see what JLCPCB can deliver.

So they agreed to proceed. But apparently, closer to the machine, there is a manual design rule check by a human auditor.

> Our auditor advised we can't print the ABS part [...]. The part will be broken at those thin area less than 1.2mm.

So I canceled the FDM ABS print. Which is a bit funny, because my home printer is a hobby grade FDM printer,
and the professional FDM printer apparently can't do what my hobby printer can.

But I am impressed by the quality assurance process. This is human work and thus costly.
Would be good if there was a design rule checker just like for the PCBs.

### Results

I ordered May 15, production started May 18 due to the checks and my overrule and finished may 20, and arrived May 31.
So a turn-around time of two weeks with slowest shipping option.

On the photos below see my home print (on the left, white), the SLA print (middle, less white) and the MJF print (right, gray).
The home print is a prototype model; the connector hole is a bit too small, and I also removed the ring around that hole.

front

side

back

The prints are great. No failures due to the thin walls, and very important, they fit LEGO pins and beams well. 
Good (fine) printing of small features.

Also the electronics fit well (bit of a push, and hard to get out). 
See here my home printed enclosure and the MJF enclosure fitted with the electronics.

model A (home)

model C (MJF)

I really like the MJF texture. Downside is of course that you do need to like that color.

(end)

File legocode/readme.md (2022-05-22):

# LEGO demo

Some examples of Python code for the LEGO Mindstorms Robot Inventor to control the SSoS device.
I assume these also run on Spike Prime.

## Numbers

This is a demo that print numbers first flush left, then flush right.

Note that the SSoS device is connected to port F of the hub.
That port is first configured as serial, next the host baudrate is set to match the one used in the SSoS device.
Note that the `mode` command actually "adds" the `baud` attribute. 
However the `mode` change takes some time, so we must have a wait in between.

The flush left number are printed in character mode (using a CLEAR-AND-HOME `\f`).

The flush right number are printed in line mode, using a CURSOR-EOLN `\t` for flush right and a LINE-COMMIT `\n`.

```python
# Number demo with Seven Segment over Serial
import hub
import utime

ssos = hub.port.F
ssos.mode( hub.port.MODE_FULL_DUPLEX )
utime.sleep_ms(500)
ssos.baud(115200)
ssos.write( b"\0") # Reset SSoS device

i = 0
while i < 1234 :
    ssos.write( b"\f"+str(i/10))
    utime.sleep_ms(100)
    i += 7
ssos.write( b"\fdone")

utime.sleep_ms(2000)
ssos.write( b"\x11") # Line mode

i = 0
while i < 1234 :
    ssos.write( b"\t"+str(i/10)+"\n")
    utime.sleep_ms(100)
    i += 7
ssos.write( b"done\n")
```

## Motor

This is a demo that print the motor position (when rotated by hand).
See a [video](https://youtu.be/2fTZVQPiG7E) of this demo.

Note that the SSoS device is connected to port F of the hub.
Here we use a more elegant way to start: 
instead of waiting 500ms after changing `mode`, we wait till the `baud` appears.

The motor is connected to port E.
The `get()` function by default reports a list of 4 numbers, 
index 2 returns "Absolute position in degrees between -180 and +179" 
(this is [mode 3](https://lego.github.io/MINDSTORMS-Robot-Inventor-hub-API/class_motor.html#Motor)).

```python
# Show motor position on Seven Segment over Serial
import hub

ssos = hub.port.F
ssos.mode( hub.port.MODE_FULL_DUPLEX )
while not hasattr(ssos, 'baud') : pass # Wait till `ssos` is serial port
ssos.baud(115200)
ssos.write( b"\0")   # Reset SSoS device
ssos.write( b"\x11") # Line mode

motor = hub.port.E.motor
while True:
    angle = motor.get()[2]
    ssos.write( b"\t"+str(angle)+"\n" )
```

motor

## Ultrasonic distance

This is a demo that prints the distance measured by an ultrasonic sensor.

Note that the SSoS device is connected to port F of the hub.
The ultrasonic sensor is connected to port A.
The `get()` function of an ultrasonic sensor reports a list of 1 numbers.
When the `FORMAT_RAW` is passed, the number seems to be the distance in millimeters.
([bast documentation](https://lego.github.io/MINDSTORMS-Robot-Inventor-hub-API/class_device.html)).
Warning: when the object is too far from the sensor, the returned distance is `None`.

```python
# Show ultrasonic sensor (port A) distance on Seven Segment over Serial (port F)
import hub

ssos = hub.port.F
ssos.mode( hub.port.MODE_FULL_DUPLEX )
while not hasattr(ssos, 'baud') : pass # Wait till `ssos` is serial port
ssos.baud(115200)
ssos.write( b"\0")   # Reset SSoS device
ssos.write( b"\x11") # Line mode

ultra = hub.port.A.device

while True:
    dist = ultra.get(ultra.FORMAT_RAW)[0]
    msg = "Far" if dist is None else str(dist)
    print(msg)
    ssos.write( b"\t"+msg+"\n" )
```

(end)

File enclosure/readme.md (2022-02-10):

# Enclosure

I made an enclosure (case) for the _Seven-Segment over Serial_ device.

model-all

## 3D modeling 

I designed the enclosure in Fusion 360, and printed it on my Cetus3D.

Here we look from the top to the bottom on the inside.

model-1

The PCB is modeled to check the fit.

model-2

The top closes the enclosure. One screw is needed (and a brass insert).

model-3

Here we look from the bottom to the top on the inside.

model-1

The PCB is modeled to check the fit.

model-2

The bottom closed the enclosure.

model-3

## STL files

Here is the STL file for the
[top](case-top.stl)

STL top.

Here is the STL file for the
[bottom](case-bottom.stl)

STL bottom.

## 3D print results

The 3D printed top and bottom and the PCB.

Components

The end result, assembled

Assembled

and with the cable

Assembled with cable

connected to the hub.

Connected to the hub

(end)

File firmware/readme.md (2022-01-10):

# Firmware

The firmware for the Arduino Nano, the controller on the SSoS board.

## Proof of Concept 1 - SFRs

A first proof-of-concept Arduino [sketch](poc1) is available.

It tests
 - Direct SFR writes
 - Timing (5ms per unit cause no visible flicker, this is 20ms per frame, or 50Hz)
 - Receiving data to print via Serial
 - Having a font

Using SFRs (Special Function Registers) means accessing hardware registers
that control the IO pins. Instead of calling `digitalWrite()`, we call
`PORTC=...`. Not only saves this the function call overhead, more importantly,
with one write to `PORTC`, we set up to 8 IO pins in one go.
See the [datasheet](https://ww1.microchip.com/downloads/en/DeviceDoc/ATmega48P_88P_168P-DS40002065A.pdf?page=102) at page 102.

## Proof of Concept 2 - Timer and ISR

A second proof-of-concept Arduino [sketch](poc2) is available.
It tests using a timer to fire an ISR every 1ms.

Notes:
 - The ATmega168 has 3 timers: timer0, timer1 and timer2. 
 - All timers depend on the system clock, normally that is 16MHz, but there is a pre-scaler between the system clock and the timer.
 - Timer0 is an 8bit timer; in Arduino it is used for e.g. `delay()` and `millis()`.
 - Timer1 is a 16bit timer; in Arduino it seems to be used for the Servo library.
 - Timer2 is an 8bit timer; in Arduino it seems to be used for `tone()`. PoC2 uses this one.

There is a fair bit of standardization by microchip in naming.
The register names but also the bitfields in the registers are introduced in the 
[datasheet](https://ww1.microchip.com/downloads/en/DeviceDoc/ATmega48P_88P_168P-DS40002065A.pdf?page=155) on page 155.
The names are also available in the Arduino header files.
In the case of the ATmega168, the header is located here (on my windows PC)
`C:\Program Files (x86)\Arduino\hardware\tools\avr\avr\include\avr\iom168p.h`.

```
TCCRnA with bits      COMnA1 COMnA0 COMnB1 COMnB0 ----- -----  WGMn1  WGMn0
TCCRnB with bits      FOCnA  FOCnB  -----  -----  WGMn2 CSn2   CSn1   CSn0
TCNTn  bits not named
OCRnA  bits not named
OCRnB  bits not named
TIMSKn                -----  -----  -----  -----  ----- OCIEnB OCIEnA TOIEn
TIFRn                 -----  -----  -----  -----  ----- OCFnB  OCFnA  TOVn
```

In the names above, replace `n` with the timer index (0, 1, or 2) - we use (timer) 2.

With registers `TCCR2A` and `TCCR2B` we set the mode (Clear Timer on Compare Match: `WGM2=010`)
and the prescaler (64 with Clock Select: `CS2=100`). 
The `TCNT2` is the actual counter, we do not read or write it (but the hardware does).

With `OCR2A` we set the value to which we want the timer to count, generate and interrupt, and clear.
Since the sustem clock (`F_CPU`) is 16MHz, and the pre-scaler is 64, timer 2 is fed with a frequency of 250 000 Hz, 
so it will increment every 4us. Therefore we need 250 increments for an interrupt every 1ms. 
We need to set `OCR2A` to 249 (because it starts counting at 0).

In `TIMSK2` we set bit `OCIE2A`, i.e. Interrupt Enable for Output Compare Match A.
This means that we have to install an ISR for `TIMER2_COMPA_vect`.
Our ISR just spikes the built-in LED, so that we can check timing on a logic analyzer.

See e.g. [Arduino 101: Timers and Interrupts](https://www.robotshop.com/community/forum/t/arduino-101-timers-and-interrupts/13072).
or [instructables](https://www.instructables.com/Arduino-Timer-Interrupts/).

```c
void setup() {
  // Setup builtin LED (it is on D13 = PB5)
  DDRB  = 1<<5; // pin PB5 as output

  // Setup timer2
  noInterrupts(); // Disable all interrupts - cli()
  TCCR2A = 0; // Do not understand why, but without first setting to 0, we get 4.063us instead of 1ms
  // Set Output Compare Register A for 1kHz (1ms)
  OCR2A = 16000000/*CPU*/  /  64/*prescaler*/  /  1000/*targetfreq*/  -  1;
  // Turn on CTC mode (Clear Timer on Compare Match) WGM2[210]=010 (so we only set WGM21)
  TCCR2A = 1 << WGM21;
  // Select prescaler of 64 with Clock Select CS2[210]=100 (so we only set CS22)
  TCCR2B = 1 << CS22;   
  // Enable timer compare interrupt
  TIMSK2 = 1 << OCIE2A;
  interrupts(); // Re-enable all interrupts - sei()
}

ISR( TIMER2_COMPA_vect ) {
  PORTB |= 1<<5; // ON
  PORTB &= ~(1<<5); // OFF
}
```

The logic analyzer shows the PoC2 is successful:

ISR 1ms

## Proof of Concept 3 - Full driver

Now that the Timer-interrupt mechanism is proven in PoC2, let's do a proof of concept for a complete driver.
We merge-in the [Python model](../isr) developed earlier.

Observe that we configured the driver as follows:

```
  uint8_t drv7s_framebuf[DRV7S_UNITCOUNT] = { 0b00000011, 0b00000100, 0b00000101, 0b00000110 };
  ...
  drv7s_brightness_set(3);
  drv7s_blinking_mode_set(1);
  drv7s_blinking_hilo_set(3,2);
  drv7s_blinking_mask_set(0b0101);
```

We hooked the logic analyzer to the four columns, the ISR beats, and (the first) 3 rows.
We captured a [Saleae trace](poc3-session.sal):

detail

Notes:
 - On the left hand side we see the labeled probes, 4 rows at the top, 3 columns at the bottom and
   the timer on the middle.
 - We see that the timer indeed fires every 1 ms (10 spikes in 10 ms).
 - We see that first col 0 is hi, then col 1, then col2, and then col 3. And that repeats.
 - This means that the frame time is 20 ms (4 units of 5 ms), a frame rate of 50 Hz.
 - We see that col 0 is hi for 3 ms and lo for the next 2. This is due to the brightness setting being 3 (out of a fixed 5).
 - When col 0 is hi, we see that the row 2 is 0, row 1 is 1 and row 0 is 1. This 011 of the frame buffer.
 - Similarly col 1 is hi while the rows are 100 (second slot in the frame buffer).

On this details level, we can not see blinking; that is on frame level.
let's zoom out.

overview

Notes:
 - On the left we see the first frame marked with 4 vertical green lines: 
   the rows are 011, 100, 101, and 110 (as we filled the frame buffer).
 - This frame is repeated 3 times - because the blinking is set to 3 hi and 2 lo.
 - The next two frames are lo. However not all units are off. 
   The mask is 0b0101, so only unit 0 and 2 shall blink, and indeed only those two are off.
 - The blinking period is 3+2, so after 5 frames the process repeats.

I do get spikes now and then (see black arrow). Spend some hours on them, but I do not understand why.
They do not cause visual artifacts...

## Real firmware

Finally, the real firmware for [SSoS](SSoS).

(end)

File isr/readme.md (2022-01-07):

# ISR model

Modeling the interrupt service routine (ISR), a part of the future firmware

## Model 1 - basic

Recall that the eight segments of the four 7-segment units are controlled in a row/column fashion.

The control cycle is as follows.
The 8 row lines are configured for unit 0, and then only the common of unit 0 is enabled.
Next, the 8 row lines are configured for unit 1, and only the common of unit 1 is enabled.
In the next step , the rows are configured for unit 2, and unit 2 is enabled.
Finally, the rows are configured for unit 3, and unit 3 is enabled.
Then control restarts with unit 0.

This means the the units are turned on one by one. 
When this happens in rapid succession, the human eye does not see the flickering.
It does mean that the units are off 3/4 of the time, which has impact on brightness.

Model 1 assumes a hardware timer triggers an interrupt service routine, which each time controls the next unit.
This guarantees no brightness variations due to timing variations.

This is the output of [model 1](isr1.py), the user displays the content `"ABCD"`.

```
user  : content 'ABCD'
system: frame is 4 ISR ticks of 5 ms, one per 7-segment unit

unit  : |0123|0123|0123|012
rows  : |ABCD|ABCD|ABCD|ABC
column: |0123|0123|0123|012

Every ISR tick, the rows and column of a (next) unit are powered
```

Each of the letters ABCD is shown 5ms, so a complete frame takes 20ms.
The unit/rows/column part is a log of the ISR; 
it shows for each tick what the rows and column is configured with.

## Model 2 - brightness

We want to support _brightness_ control.
This means that each unit should be on a fraction of the 5ms. 
To achieve this, we split the 5ms in 5 _slots_ of 1ms.

This is the output of [Model 2](isr2.py), the user selects a brightness of 2 out of 5.

```
user  : content 'ABCD', brightness 2/5
system: frame is 20 ISR ticks of 1 ms (5 brightness levels for 4 units)

slot  : |01234 01234 01234 01234|01234 01234 0
unit  : |00000 11111 22222 33333|00000 11111 2
rows  : |AAAAA BBBBB CCCCC DDDDD|AAAAA BBBBB C
column: |00--- 11--- 22--- 33---|00--- 11--- 2

The column is only on during 2 of 5 ISR ticks due to brightness setting
```

## Model 3 - blinking

We want to support _blinking_. 
Of course the host could send `"ABCD"`, `"    "`, `"ABCD"`, `"    "` etc, but that burdens the host.
We want to offload the host and have the SSoS device take care of blinking.

This is the output of [Model 3](isr3.py). 

```
user  : content 'ABCD', brightness 1/5, blink=3/5
system: frame is 20 ISR ticks of 1 ms (5 brightness levels for 4 units), blinking period is 5 frames

slot  : [01234 01234 01234 01234|01234 01234 01234 01234|01234 01234 01234 01234|01234 01234 01234 01234|01234 01234 01234 01234][01234
unit  : [00000 11111 22222 33333|00000 11111 22222 33333|00000 11111 22222 33333|00000 11111 22222 33333|00000 11111 22222 33333][00000
frame : [00000 00000 00000 00000|11111 11111 11111 11111|22222 22222 22222 22222|33333 33333 33333 33333|44444 44444 44444 44444][00000
rows  : [AAAAA BBBBB CCCCC DDDDD|AAAAA BBBBB CCCCC DDDDD|AAAAA BBBBB CCCCC DDDDD|DDDDD DDDDD DDDDD DDDDD|DDDDD DDDDD DDDDD DDDDD][AAAAA
column: [0---- 1---- 2---- 3----|0---- 1---- 2---- 3----|0---- 1---- 2---- 3----|----- ----- ----- -----|----- ----- ----- -----][0----

For brightness, column is only on 1 of 5 ISRs; for blinking 3 of 5 frames
```

The user selected a blinking period of 5 frames, of which 0, 1 and 2 are on (and 3 and 4 off).
The user also has a brightness level of 1/5.

## Model 4 - blink exemption

We want to enable blinking for _only a part_ of the display.

This is the output of [Model 4](isr4.py). 
The user exempted units 0 and 2 (the `noblink` mask).

```
user  : content 'ABCD', brightness 4/5, blink=0b101-3/5
system: frame is 20 ISR ticks of 1 ms (5 brightness levels for 4 units), blinking period is 5 frames

slot  : [01234 01234 01234 01234|01234 01234 01234 01234|01234 01234 01234 01234|01234 01234 01234 01234|01234 01234 01234 01234][01234
unit  : [00000 11111 22222 33333|00000 11111 22222 33333|00000 11111 22222 33333|00000 11111 22222 33333|00000 11111 22222 33333][00000
frame : [00000 00000 00000 00000|11111 11111 11111 11111|22222 22222 22222 22222|33333 33333 33333 33333|44444 44444 44444 44444][00000
rows  : [AAAAA BBBBB CCCCC DDDDD|AAAAA BBBBB CCCCC DDDDD|AAAAA BBBBB CCCCC DDDDD|AAAAA AAAAA CCCCC CCCCC|AAAAA AAAAA CCCCC CCCCC][AAAAA
column: [0000- 1111- 2222- 3333-|0000- 1111- 2222- 3333-|0000- 1111- 2222- 3333-|0000- ----- 2222- -----|0000- ----- 2222- -----][0000-

For brightness, column is only on 4 of 5 ISRs; for blinking 3 of 5 frames, but on for non-blinking units in last 2 frames
```

Here we see that frame 3 and 4 (blink off) does not drive unit 1 and 3, but it does drive unit 0 and 2 (exempted).

(end)

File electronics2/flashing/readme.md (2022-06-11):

# Flashing the SSoSS

This page describes how to program the SSoSS board - that is not trivial, because the mounted ATmega328PB has no bootloader.

SSoSS

## Introduction

The board that came back from [JLCPCB](https://jlcpcb.com/DMP) has an ATmega328PB straight from the factory.
In other words, it does _not_ have a bootloader.
That is the reason I added an [ICSP](https://en.wikipedia.org/wiki/In-system_programming) (In-Circuit Serial Programming) header to the board.
It allows low-level access to the flash.

We need a so-called _programmer_ to connect a PC to the board to program the ATmega328PB.

You can buy a programmer, but you can also convert an Arduino Nano (or Uno) into a programmer, 
see https://www.instructables.com/Burn-a-New-Bootloader-Arduino-Pro-Mini. That is what we are going to do.
This allows us to use `avrdude` on the PC to "mess around" in the _target_.
The tool avrdude is actually integrated in the Arduino IDE, so you have it and are using it without knowing.

programmer

This messing around could be: flashing your own application, setting internal fuses, or flashing a bootloader.

Flashing the application is what we are after.

You might wonder what the fuses are. Those are bits in some non-volatile memory that 
[configure features in the MCU](https://circuitdigest.com/microcontroller-projects/understanding-fuse-bits-in-atmega328p-to-enhance-arduino-programming-skills).
The name "fuse" is misleading: by default they are 1, the programmer
can clear them to 0, but the programmer can also set them back to 1.
So they are not one-time fuses. Still they are tricky, because some fuse settings
have dangerous effects. For example there is a fuse that disables reset; but without reset the programmer
can not connect to the fuses!

We can also flash a bootloader (in the lower part of the flash). 
With that, we no longer need a programmer; a USB-to-serial adapter suffices.
Avrdude then sends commands via the _serial port_ to the bootloader running on the target
instead of directly touching the memories.
Those commands tell the bootloader to flash the user application in the (upper part of the) flash.

This is what most Arduino boards (Uno, Nano) use.

programmer

## Making an ICSP programmer

First we need a _programmer_. 

We will convert a standard Arduino Nano to a programmer by flashing an appropriate piece of firmware.

 - Connect the Nano (the programmer to be) to the PC (using USB).
 - Open the Arduino IDE (I'm using 1.8.13, May 2022).
 - In the Tools menu make sure
   - `Board` is `Nano` (`Tools -> Board -> Arduino AVR Boards > Arduino Nano`) - an Uno would also work if you have that.
   - `Processor` is `ATmega328P (Old Bootloader)` - maybe yours has the new bootloader.
   - `Port` is `COM5` - or whatever the USB port of your Nano is.
 - Load the **programmer** sketch: `File -> Examples -> 11.ArduinoISP -> ArduinoISP`.
 - Compile and upload the programmer sketch by pressing the Upload button (or `Sketch > Upload`).

The Nano is now a programmer (type `Arduino [as] ISP`).

## Wiring the programmer to a target
Secondly, we need to wire the programmer (the Nano) to the target board, in our case the SSoSS board.
The connection basically consists of connecting the ICSP headers one-to-one, RESET being the exception.

Connect
 - VCC:   Nano-programmer.VCC to target-SSoSS.VCC
 - GND:   Nano-programmer.GND to target-SSoSS.GND
 - MOSI:  Nano-programmer.D11 to target-SSoSS.D11
 - MISO:  Nano-programmer.D12 to target-SSoSS.D12
 - SCK:   Nano-programmer.D13 to target-SSoSS.D13
 - RESET: Nano-programmer.**D10** to target-SSoSS.**RSTn**

Wiring

This is the pinout of the ICSP header.
The dot in the lower right corner, of both boards, indicates pin 1.

```text
            +----+
        GND |6  5| RSTn
 (D11) MOSI |4  3| SCK (D13)
        VCC |2  1| MISO (D12)
            +----+°
```         

## Flashing

Thirdly, with the programmer connected to the target, we can flash the target.
There are two options:
 - Use the programmer to flash a **bootloader** to the target. 
 - Use the programmer to flash an **application** to the target.

### Flashing the bootloader using Arduino IDE

We can use the programmer to flash a bootloader.
We can even do that from the Arduino IDE; I believe this also programs the fuses.

It is important that the IDE knows the target MCU, so it can flash the appropriate bootloader using the correct method.
 - We have the target board (SSoSS) connected with the 6 wires to the programmer (Nano) as described above.
 - We connect the programmer (Nano) to the PC.
 - On the PC we start the Arduino IDE with an empty project.
 - We must setup the correct target in the Tools menu.
   - `Board` is `Arduino Pro or Pro Mini` - this is the board closest to the SSoSS.
   - `Processor` is `ATmega328P (3.3V, 8MHz)` - the board has an 8MHz oscillator and will run on 3V3 (although now it runs on 5V from USB).
   - `Port` is the port the programmer is connected to (`COM5` in my example)
   - `Programmer` must be set `Arduino as ISP` - that is what we just flashed in the Nano.

Now, do not make the mistake to press Upload, that will compile and flash the current (empty?) project
to the Nano. Instead, we select `Tools > Burn Bootloader`.

Burn bootloader

I suggest that before you fire up the burning, you select
`File > Preferences > Show verbose output during: > upload`. 
Then this is the result.

```txt
C:\Users\maarten\AppData\Local\Arduino15\packages\arduino\tools\avrdude\6.3.0-arduino17/bin/avrdude -CC:\Users\maarten\AppData\Local\Arduino15\packages\arduino\tools\avrdude\6.3.0-arduino17/etc/avrdude.conf -v -patmega328p -cstk500v1 -PCOM5 -b19200 -e -Ulock:w:0x3F:m -Uefuse:w:0xFD:m -Uhfuse:w:0xDA:m -Ulfuse:w:0xFF:m 

avrdude: Version 6.3-20190619
         Copyright (c) 2000-2005 Brian Dean, http://www.bdmicro.com/
         Copyright (c) 2007-2014 Joerg Wunsch

         System wide configuration file is "C:\Users\maarten\AppData\Local\Arduino15\packages\arduino\tools\avrdude\6.3.0-arduino17/etc/avrdude.conf"

         Using Port                    : COM5
         Using Programmer              : stk500v1
         Overriding Baud Rate          : 19200
         AVR Part                      : ATmega328P
         Chip Erase delay              : 9000 us
         PAGEL                         : PD7
         BS2                           : PC2
         RESET disposition             : dedicated
         RETRY pulse                   : SCK
         serial program mode           : yes
         parallel program mode         : yes
         Timeout                       : 200
         StabDelay                     : 100
         CmdexeDelay                   : 25
         SyncLoops                     : 32
         ByteDelay                     : 0
         PollIndex                     : 3
         PollValue                     : 0x53
         Memory Detail                 :

                                  Block Poll               Page                       Polled
           Memory Type Mode Delay Size  Indx Paged  Size   Size #Pages MinW  MaxW   ReadBack
           ----------- ---- ----- ----- ---- ------ ------ ---- ------ ----- ----- ---------
           eeprom        65    20     4    0 no       1024    4      0  3600  3600 0xff 0xff
           flash         65     6   128    0 yes     32768  128    256  4500  4500 0xff 0xff
           lfuse          0     0     0    0 no          1    0      0  4500  4500 0x00 0x00
           hfuse          0     0     0    0 no          1    0      0  4500  4500 0x00 0x00
           efuse          0     0     0    0 no          1    0      0  4500  4500 0x00 0x00
           lock           0     0     0    0 no          1    0      0  4500  4500 0x00 0x00
           calibration    0     0     0    0 no          1    0      0     0     0 0x00 0x00
           signature      0     0     0    0 no          3    0      0     0     0 0x00 0x00

         Programmer Type : STK500
         Description     : Atmel STK500 Version 1.x firmware
         Hardware Version: 2
         Firmware Version: 1.18
         Topcard         : Unknown
         Vtarget         : 0.0 V
         Varef           : 0.0 V
         Oscillator      : Off
         SCK period      : 0.1 us

avrdude: AVR device initialized and ready to accept instructions

Reading | ################################################## | 100% 0.04s

avrdude: Device signature = 0x1e9516 (probably m328pb)
avrdude: Expected signature for ATmega328P is 1E 95 0F
         Double check chip, or use -F to override this check.

avrdude done.  Thank you.

Error while burning bootloader.
```

Normally, this would work. Unfortunately, we get an error.
The error is at the end: `Device signature = 0x1e9516 (probably m328pb), Expected signature for ATmega328P is 1E 95 0F`.
Damn, I put a non-standard ATmega328 on the SSoSS, the PB variant instead of the B variant.

The reason I did this, was that the B variant was not available at LCSC, but the PB variant was.
I did check the differences of [ATmega328PB vs ATmega328P](https://onlinedocs.microchip.com/pr/GUID-CBDC1838-0100-4F26-A45A-134958193C3B-en-US-4/index.html)

> ATmega328PB is not a drop-in replacement for ATmega328 variants, but a new device. 
> However, the functions are backward compatible with the existing ATmega328 functions. 
> Existing code for these devices will work in the new devices without changing existing configuration or enabling new functions. 
> The code that is available for your existing ATmega328 variants will continue to work on the new ATmega328PB device.

My conclusion back when I selected it: slightly different footprint, but software-wise backward compatible.
Now I know that the Arduino IDE can't burn the bootloader.

But maybe avrdude can...

> **Note** the core problem is that no Arduino board has the ATMega328PB.
> I did find an Arduino IDE compatible board from [polulu](https://www.pololu.com/docs/0J74/4.3) with the PB.
> However, it turned out that it is not well enough integrated to make the `Burn bootloader` work.

So let's try avrdude.

### Flashing the bootloader using avrdude

The very first line of the upload in the console is as follows (I added line breaks for readability).
```
  C:\Users\maarten\AppData\Local\Arduino15\packages\arduino\tools\avrdude\6.3.0-arduino17/bin/avrdude 
      -CC:\Users\maarten\AppData\Local\Arduino15\packages\arduino\tools\avrdude\6.3.0-arduino17/etc/avrdude.conf
      -v -patmega328p -cstk500v1 -PCOM5 -b19200 -e 
      -Ulock:w:0x3F:m -Uefuse:w:0xFD:m -Uhfuse:w:0xDA:m -Ulfuse:w:0xFF:m 
```

Let's check the [avrdude manual](https://man.archlinux.org/man/community/avrdude/avrdude.1.en)
(or [adafruit](https://www.ladyada.net/learn/avr/avrdude.html)).
We learn
 - `avrdude` executable is located in `C:\Users\maarten\AppData\Local\Arduino15\packages\arduino\tools\avrdude\6.3.0-arduino17\bin`.
 - The `-C` passes a config-file that contains all programmer and part definitions that avrdude knows about. 
 - `-v` enabls verbose output.
 - `-p partno` is the only option that is mandatory, we see that `atmega328p` is passed instead of `patmega328pb`.  
   This is the **root cause of the error**.
 - `-c programmer-id`; Atmel's default programmer is the STK500 programmer, and that seems the one being used (in the Nano presumably).
 - `P port` identifies the serial port to which the programmer is attached.
 - `-b baudrate`, confuses me: we are using SPI, not RS-232, which the avrdude manual mentions.
 - `-e` causes a chip erase to be executed. This is a relevant observation: 
   the entire flash is erased, including any bootloader that might already be there.

Next come the important parameters, the `U`s.
These parameters encode writes to non-volatile memories.
Here the `U`s write the fuses. 
 - There are four of them `lock`, `efuse`, `hfuse`, and `lfuse`.
   The avrdude manual explains: lock is the lock byte, efuse is the extended fuse byte, hfuse is the high fuse byte, lfuse is the low fuse byte.
 - The argument of `U` is `memtype:op:data:format`
   - `memtype` is either `flash` or `eeprom`, or `lock`, `hfuse`, `lfuse`, or `efuse`, ...
   - after the `:` comes `op`: `r`, `w`, or `v` meaning you can read (r), write (w), or verify (v).
   - after the next `:` comes data, an inline value or a filename.
   - a final `:` gives the format, important is `m` for immediate (inline) value, or `i` for intel hex encoded file.

**Conclusion**: "flashing the bootloader" does not flash the bootloader, it just flashes the fuses. 

Let's check what the IDE tried to write to the fuses.

One explanation is on this [page](https://circuitdigest.com/microcontroller-projects/understanding-fuse-bits-in-atmega328p-to-enhance-arduino-programming-skills).
However, it is for the ATMega328P, so better to check the [ATMega328PB datasheet](https://ww1.microchip.com/downloads/en/DeviceDoc/40001906C.pdf)
(do not use the old 2017 revision A datasheet, but at least the 2018 revision C datasheet).

**Please note that one aspect is rather confusing for fuses**: a 1 in a fuse bit is referred to as "unprogrammed". In other words, fuse bits are "low-active".

What does the command write?

 - lock to 0x3F or `0011 1111`  
 
   lock byte

   The ATmega328PB uses the lower 6 bits only. 
   Writing a 0 in one of those 6 activates some lock such as "programming of the Flash and EEPROM is disabled".
   I don't want or need to lock my firmware - it's on github :-) anyhow.
   
   The value 0b0011_1111 or 0x3F makes sense for my lock byte (nothing locked).
   
 - efuse to 0xFD or `1111 1101`  
 
   efuse byte

   The "Extended Fuse" byte has two bit-fields:
   
   - bit 3 set to `1` - `CFD` (disable Clock Failure detection). This is "new", i.e. not in ATmega328P.  By default this is 0, programmed, disabled, but the command would enable it.
   - bit 2,1,0 set to `101` - `BODLEVEL` (Brown-Out LEVEL). The command sets BODLEVEL to `101` meaning 2.5V .. 2.9V, which sounds good for an 3V3 supply.
     efuse byte BODLEVEL
   
   I think I want 0b1111_0101 or 0xF5 for the efuse (also disable CFD).
   
 - hfuse to 0xDA or `1101 1010`  
 
   hfuse byte
   
   The "High Fuse" byte has 7 bit fields:
   
   - bit   7 set to `1` - `RSTDISBL` (external ReSeT DISabLe) 
     disables the external hardware reset pin. 
     1 means `unprogrammed` (disable not active, so reset enabled). 
     **Writing 0 can brick your device.**
     
   - bit   6 set to `1` - `DWEN` (Debug Wire ENable) 
     HW feature used to program/debug with a single wire; you will need special hardware.  
     1 means `unprogrammed` (so not enabled).
     
   - bit   5 set to `0` - `SPIEN` (SPI ENable) 
     enables the SPI programming interface. This is what we use over ICSP. 
     0 means programmed, i.e. SPI enabled. 
     **Writing 1 can brick your device.**
     
   - bit   4 set to `1` - `WDTON` (Watch Dog ON) 
     enables the watchdog. 
     1 means `unprogrammed` (no watchdog).
     
   - bit   3 set to `1` - `EESAVE` (EEprom SAVE) 
     the EEPROM memory is preserved through chip erase. 
     1 means `unprogrammed` (EEPROM also erased).
     
   - bit 2,1 set to `01` - `BOOTSZ` (BOOT SiZe) 
     refers to the amount of memory reserved for the bootloader. 
     The command writes `01` to have 16 pages of 64 words or 1024 words (2048 bytes) for the bootloader. 
     Default is `00` which is **bigger**: 2048 words (4096 bytes).
     
     hfuse byte BOOTSZ
     
   - bit   0 set to `0` - `BOOTRST` (BOOT ReSeT vector). 
     The Reset vector can be moved to the start of the boot Flash section by programming the BOOTRST Fuse. 
     The command writes `0`, i.e. using the bootloader area.
     
     hfuse byte BOOTRST
   
   I think I want 0b1101_1110 or 0xDE for the hfuse (smallest space for bootloader).
   
 - lfuse to 0xFF or `1111 1111`  
 
   lfuse byte
 
   The "Low Fuse" byte has four fields:
   
   - bit    7 set to `1` - CKDIV8 (ClocK DIVide by 8). 
     1 means `unprogrammed`, so not divided by 8.
     
   - bit    6 set to `1` - CKOUT (ClocK OUTput) 
     allows the system clock to be output on PORTB0, I guess for checking the system. 
     1 means `unprogrammed` (not output).
     
   - bit   54 set to `11` - SUT (Start-Up Time).
     I believe it makes sense that bit 0/CKSEL0 is prepended to SUT.
   
     lfuse byte SUT
     
     Looking at the three bits CKSEL0/SUT1/SUT0, the command sets them to `111`.
     This configuration results in maximum start-up time 16k plus 19k clock cycles plus 65ms.
     For an 8MHz clock, 35k cycles is 4.5ms, so total delay is just below 70ms. 
     Looks safe and not unusable long.
     And we do have an external oscillator who presumably needs some time to settle. 
     
   - bit 3210 set to `1111` - CKSEL (ClocK source SELect). 
   
     The default of 0010 for CKSEL[3:0] results in internal RC Oscillator at 8 MHz as seen in the following table
     
     lfuse byte CKSEL
     
     The command tries to write 1111; this means "Low Power Crystal Oscillator", and that sounds good.

   I think I'm happy with the 0b1111_1111 or 0xFF for the lfuse.

Summarizing, the command tried to write
 - lock to 0x3F or `0011 1111` and I agree on `xx11 1111`.
 - efuse to 0xFD or `1111 1101` but I prefer `1111 0101` or 0xF5 (also disable CFD).
 - hfuse to 0xDA or `1101 1010` but I prefer `1101 1110` or 0xDE (smallest space for bootloader).
 - lfuse to 0xFF or `1111 1111` and I agree.

The write command failed.
However, as we see later, I do have the fuses at the values I want, not sure why; safe defaults?

```text
avrdude: safemode: lfuse reads as FF
avrdude: safemode: hfuse reads as DE
avrdude: safemode: efuse reads as F5
```

Conclusion: we do not need to burn the bootlader (or the fuse bits), 
we will directly flash the application.

### Flashing the application using avrdude

The Tools menu shows how the compiler should build (`Board`, `Processor`).
It also shows how the (hidden) avrdude shall communicate (`Port`) to the board when executing Upload.
It also has `Programmer`, this is normally NOT used. It is only used when selecting `Burn Bootlader`.

Tools menu

It turns out that the latter is not completely true. 
The Sketch menu has an entry I always ignored: `Upload Using Programmer`.

Sketch menu

With the [ledtest](ledtest) sketch loaded in the IDE, and the same settings in `Tools` as before, namely
 - `Board` is `Arduino Pro or Pro Mini` - this is the board closest to the SSoSS.
 - `Processor` is `ATmega328P (3.3V, 8MHz)` - the board has an 8MHz oscillator and will run on 3V3 (although now it run son 5V).
 - `Port` is the port the programmer is connected to (`COM5` in my example)
 - `Programmer` must be set `Arduino as ISP` - that is what we flashed in the Nano to make it a programmer.

We now try `Sketch > Upload Using Programmer`.

I suggest that before you flash, you select
`File > Preferences > Show verbose output during: > upload`. 
Then this is the result.

```text
Sketch uses 2200 bytes (7%) of program storage space. Maximum is 30720 bytes.
Global variables use 202 bytes (9%) of dynamic memory, leaving 1846 bytes for local variables. Maximum is 2048 bytes.
C:\Users\maarten\AppData\Local\Arduino15\packages\arduino\tools\avrdude\6.3.0-arduino17/bin/avrdude -CC:\Users\maarten\AppData\Local\Arduino15\packages\arduino\tools\avrdude\6.3.0-arduino17/etc/avrdude.conf -v -patmega328p -cstk500v1 -PCOM5 -b19200 -Uflash:w:C:\Users\maarten\AppData\Local\Temp\arduino_build_617119/ledtest.ino.hex:i 

avrdude: Version 6.3-20190619
         Copyright (c) 2000-2005 Brian Dean, http://www.bdmicro.com/
         Copyright (c) 2007-2014 Joerg Wunsch

         System wide configuration file is "C:\Users\maarten\AppData\Local\Arduino15\packages\arduino\tools\avrdude\6.3.0-arduino17/etc/avrdude.conf"

         Using Port                    : COM5
         Using Programmer              : stk500v1
         Overriding Baud Rate          : 19200
         AVR Part                      : ATmega328P
         Chip Erase delay              : 9000 us
         PAGEL                         : PD7
         BS2                           : PC2
         RESET disposition             : dedicated
         RETRY pulse                   : SCK
         serial program mode           : yes
         parallel program mode         : yes
         Timeout                       : 200
         StabDelay                     : 100
         CmdexeDelay                   : 25
         SyncLoops                     : 32
         ByteDelay                     : 0
         PollIndex                     : 3
         PollValue                     : 0x53
         Memory Detail                 :

                                  Block Poll               Page                       Polled
           Memory Type Mode Delay Size  Indx Paged  Size   Size #Pages MinW  MaxW   ReadBack
           ----------- ---- ----- ----- ---- ------ ------ ---- ------ ----- ----- ---------
           eeprom        65    20     4    0 no       1024    4      0  3600  3600 0xff 0xff
           flash         65     6   128    0 yes     32768  128    256  4500  4500 0xff 0xff
           lfuse          0     0     0    0 no          1    0      0  4500  4500 0x00 0x00
           hfuse          0     0     0    0 no          1    0      0  4500  4500 0x00 0x00
           efuse          0     0     0    0 no          1    0      0  4500  4500 0x00 0x00
           lock           0     0     0    0 no          1    0      0  4500  4500 0x00 0x00
           calibration    0     0     0    0 no          1    0      0     0     0 0x00 0x00
           signature      0     0     0    0 no          3    0      0     0     0 0x00 0x00

         Programmer Type : STK500
         Description     : Atmel STK500 Version 1.x firmware
         Hardware Version: 2
         Firmware Version: 1.18
         Topcard         : Unknown
         Vtarget         : 0.0 V
         Varef           : 0.0 V
         Oscillator      : Off
         SCK period      : 0.1 us

avrdude: AVR device initialized and ready to accept instructions

Reading | ################################################## | 100% 0.05s

avrdude: Device signature = 0x1e9516 (probably m328pb)
avrdude: Expected signature for ATmega328P is 1E 95 0F
         Double check chip, or use -F to override this check.

avrdude done.  Thank you.

Wrong microcontroller found.  Did you select the right board from the Tools > Board menu?
```

Same error as before: wrong micro controller.

But this is not about scary fuse bits. Can we flash the application using avrdude?

Again let's disect the first line.

```cmd
C:\Users\maarten\AppData\Local\Arduino15\packages\arduino\tools\avrdude\6.3.0-arduino17/bin/avrdude 
  -CC:\Users\maarten\AppData\Local\Arduino15\packages\arduino\tools\avrdude\6.3.0-arduino17/etc/avrdude.conf 
  -v -patmega328p -cstk500v1 -PCOM5 -b19200 
  -Uflash:w:C:\Users\maarten\AppData\Local\Temp\arduino_build_617119/ledtest.ino.hex:i 
```

We recognize all parameters from before.
And indeed the `-U` is no longer about fuse bits, but about the application hex file `ledtest.ino.hex` in intel hex (`:i`).

Let's execute this line with `-patmega328pb`. 
But first we need the hex file. 
We can obtain it in from the same menu with `Export compiled Binary`.

export.

This runs a compile, and saves the hex file in the project dir.

project dir

I was surprised at first that there are _two_ hex files.
 - `ledtest.ino.eightanaloginputs.hex` - this is the `ledtest` application only. 
    For some reason, the `eightanaloginputs` describes a variant (not relevant).
 - `ledtest.ino.with_bootloader.eightanaloginputs.hex` - this is the `ledtest` application and the bootloader. 
   If you use ICSP to flash, the entire flash is wiped, so you might want to flash the bootloader.
   If you use TX/RD to flash, the bootloader only flashes the application part, so you need the file without bootloader.
 
I made a bat file [icsp.bat](ledtest/icsp.bat) with the avrdude call, replacing the `-patmega328p` with `-patmega328pb`.
I also factored out the path to avrdude.

Running the batch file finally gives success:

```cmd
C:\Users\maarten\Desktop\flashing\ledtest>icsp.bat

C:\Users\maarten\Desktop\flashing\ledtest>SET AVRDUDE=C:\Users\maarten\AppData\Local\Arduino15\packages\arduino\tools\avrdude\6.3.0-arduino17

C:\Users\maarten\Desktop\flashing\ledtest>C:\Users\maarten\AppData\Local\Arduino15\packages\arduino\tools\avrdude\6.3.0-arduino17\bin\avrdude -CC:\Users\maarten\AppData\Local\Arduino15\packages\arduino\tools\avrdude\6.3.0-arduino17\etc\avrdude.conf -v -patmega328pb -cstk500v1 -PCOM5 -b19200 -Uflash:w:ledtest.ino.with_bootloader.eightanaloginputs.hex:i

avrdude: Version 6.3-20190619
         Copyright (c) 2000-2005 Brian Dean, http://www.bdmicro.com/
         Copyright (c) 2007-2014 Joerg Wunsch

         System wide configuration file is "C:\Users\maarten\AppData\Local\Arduino15\packages\arduino\tools\avrdude\6.3.0-arduino17\etc\avrdude.conf"

         Using Port                    : COM5
         Using Programmer              : stk500v1
         Overriding Baud Rate          : 19200
         AVR Part                      : ATmega328PB
         Chip Erase delay              : 9000 us
         PAGEL                         : PD7
         BS2                           : PC2
         RESET disposition             : dedicated
         RETRY pulse                   : SCK
         serial program mode           : yes
         parallel program mode         : yes
         Timeout                       : 200
         StabDelay                     : 100
         CmdexeDelay                   : 25
         SyncLoops                     : 32
         ByteDelay                     : 0
         PollIndex                     : 3
         PollValue                     : 0x53
         Memory Detail                 :

                                  Block Poll               Page                       Polled
           Memory Type Mode Delay Size  Indx Paged  Size   Size #Pages MinW  MaxW   ReadBack
           ----------- ---- ----- ----- ---- ------ ------ ---- ------ ----- ----- ---------
           eeprom        65    20     4    0 no       1024    4      0  3600  3600 0xff 0xff
           flash         65     6   128    0 yes     32768  128    256  4500  4500 0xff 0xff
           lfuse          0     0     0    0 no          1    0      0  4500  4500 0x00 0x00
           hfuse          0     0     0    0 no          1    0      0  4500  4500 0x00 0x00
           efuse          0     0     0    0 no          1    0      0  4500  4500 0x00 0x00
           lock           0     0     0    0 no          1    0      0  4500  4500 0x00 0x00
           calibration    0     0     0    0 no          1    0      0     0     0 0x00 0x00
           signature      0     0     0    0 no          3    0      0     0     0 0x00 0x00

         Programmer Type : STK500
         Description     : Atmel STK500 Version 1.x firmware
         Hardware Version: 2
         Firmware Version: 1.18
         Topcard         : Unknown
         Vtarget         : 0.0 V
         Varef           : 0.0 V
         Oscillator      : Off
         SCK period      : 0.1 us

avrdude: AVR device initialized and ready to accept instructions

Reading | ################################################## | 100% 0.03s

avrdude: Device signature = 0x1e9516 (probably m328pb)
avrdude: safemode: lfuse reads as FF
avrdude: safemode: hfuse reads as DE
avrdude: safemode: efuse reads as F5
avrdude: NOTE: "flash" memory has been specified, an erase cycle will be performed
         To disable this feature, specify the -D option.
avrdude: erasing chip
avrdude: reading input file "ledtest.ino.with_bootloader.eightanaloginputs.hex"
avrdude: writing flash (32652 bytes):

Writing | ################################################## | 100% 2.89s

avrdude: 32652 bytes of flash written
avrdude: verifying flash memory against ledtest.ino.with_bootloader.eightanaloginputs.hex:
avrdude: load data flash data from input file ledtest.ino.with_bootloader.eightanaloginputs.hex:
avrdude: input file ledtest.ino.with_bootloader.eightanaloginputs.hex contains 32652 bytes
avrdude: reading on-chip flash data:

Reading | ################################################## | 100% 1.75s

avrdude: verifying ...
avrdude: 32652 bytes of flash verified

avrdude: safemode: lfuse reads as FF
avrdude: safemode: hfuse reads as DE
avrdude: safemode: efuse reads as F5
avrdude: safemode: Fuses OK (E:F5, H:DE, L:FF)

avrdude done.  Thank you.

C:\Users\maarten\Desktop\flashing\ledtest>
```

And indeed, the small patch of passing the correct MCU ID fixed the problem.

And we get feedback on the fuses - they are exactly as we want them (see previous section)!

Here you see [one LED blinking](https://youtu.be/dpqHkJS7RNk) to prove that the flashing worked.

I soldered all resistors at the front side - [JLCPCB](https://jlcpcb.com/DMP) will only mount components
on one side. I moved a spare LED around to check that all segments resistors are correctly soldered.
I want a successful test before I solder the 7-segments since they overlay the resistors.

## Problems

Looking at the [video of the blinking LED](https://youtu.be/dpqHkJS7RNk) you might think we're done.
But I still have a problem. The LED driven by the app starts blinking after flashing, but after _power-on_ it doesn't.

Solved it! 
I changed [icsp.bat](ledtest/icsp.bat) not to flash `ledtest.ino.with_bootloader.eightanaloginputs.hex`, 
but to flash `ledtest.ino.eightanaloginputs.hex`.
Without flashing the bootloader the board runs my ledtest app when powered on!

Next, I flashed the official [SSoS firmware](../../firmware/SSoS) - I added a similar flash script.
Flashing works, booting works, good.

But the display flickers.
It is hard to see on the [video](https://youtu.be/p-Qe8X2YwIE).
My first guess: fuses need tweaking to get a faster clock.
Bit let's measure.

The standard firmware shows `SSoS` on power up. I put a probe on Segment A.
It should be high for unit 0, 1, not for 2 and again for 3.
The logic analyzer confirms that, see the blue rectangle that encircles one frame (4 units).

timing

But we also see that each unit gets 10ms, and thus the whole frame 40ms instead of 20ms.
At 20ms (50Hz), flicker is not visible, but at 40ms (25Hz) it is.

Found the bug.
The driver [drv7s.cpp](../../firmware/SSoS/drv7s.cpp#L157) had hard-wired the clock frequency:

```c++
OCR2A = 16000000/*CPU*/  /  64/*prescaler*/  /  1000/*targetfreq*/  -  1;
```

and I now changed that to use the system macro `F_CPU`, which is 
8000000 if we compile for `Board` the `Arduino Pro or Pro Mini` and `Processor` at `ATmega328P (3.3V, 8MHz)`.

```c++
OCR2A = F_CPU/*CPU*/  /  64/*prescaler*/  /  1000/*targetfreq*/  -  1;
```

(end)

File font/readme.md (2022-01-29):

# Font

The SSoS device contains a firmware with two fonts.
This directory contains a Python project to tabulate the fonts.
Actually two tables are generated, one mapping ASCII to 7-segment patterns,
and one mapping 7-segment patterns to ASCII.
The latter helps in identifying duplicates (e.g. 5 and S).

## Unique7s
The first font is named _Unique7s_. 
It maps all ASCII characters to a 7-segment display. 
The crucial design decision is that every ASCII character maps to a _unique_ display pattern. 
It makes some characters hard to read (see uppercase S or lower case f).
  
This is the ASCII table:
  
ASCII table
  
This is a systematic overview of all 7-segment patterns.
Note that unused patterns are green.

Patterns table

## LookAlike7s

The second font is named _LookAlike7s_. 
It maps all ASCII characters to a 7-segment display. 
The crucial design decision is each character is mapped to a 7-segment pattern that is as close as possible to what the character normally looks like. 
The downside is that one pattern may be used for several characters (see 5, uppercase S and lowercase s).

This is the ASCII table. Duplicates are shown in red.
  
ASCII table
  
This is a systematic overview of all 7-segment patterns:

Patterns table

## Use the script
To use the script yourself (on Windows) you need:

- Python (3.8+) on your system (add `setup.bat` to tweak the path to `python.exe`)
- Start with an empty project directory; then copy `requirements.txt`, `setup.bat`, `run.bat`, and `tables.py` into it.
- Run `setup.bat` to create a virtual Python environment (in sub-directory `env` in the project directory). 
  Note that packages will be installed in the virtual environment, as listed in `requirements.txt`.
- Run `run.bat` to generate the tables.
- Change the font definitions in `tables.py` if you want to alter the fonts.

(end)

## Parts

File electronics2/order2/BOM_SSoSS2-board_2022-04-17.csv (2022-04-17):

ID | Name | Designator | Footprint | Quantity | Manufacturer Part | Manufacturer | Supplier | Supplier Part | Price
1 | 220Ω | RA,RB,RC,RD,RE,RF,RG,RP | R0805 | 8 | 0805W8F2200T5E | UniOhm | LCSC | C17557 | 0.002
2 | 7-SEGMENT-DISPLAYPTH | M0,M1,M2,M3 | 7-SEGMENT-DISPLAY | 4
3 | 100nF | C1,C2 | C0402_NEW | 2 | CL05B104KO5NNNC | SAMSUNG | LCSC | C1525 | 0.001
4 | ATMEGA328PB-AU | U2 | TQFP-32_L7.0-W7.0-P0.80-LS9.0-BL | 1 | ATMEGA328PB-AU | MICROCHIP | LCSC | C132230 | 9.661
5 | 8MHz | X1 | OSC-SMD_3P-L3.2-W1.3-P1.2-L | 1 | CSTNE8M00G55A000R0 | Murata Electronics | LCSC | C341523 | 0.315
6 | 4.7uF | C3 | C0603 | 1 | CL10A475KO8NNNC | SAMSUNG | LCSC | C19666 | 0.011
7 | 47uF | C4 | C0805 | 1 | CL21A476MQYNNNE | SAMSUNG | LCSC | C16780 | 0.026
8 | HDR-M-2.54_2x3 | J1 | HDR-M-2.54_2X3 | 1 |  |  | LCSC | C65114 | 0.03
9 | HDR-IDC-2.54-2X3P | J2 | HDR-IDC-2.54-2X3P | 1 | 2X3 2.54mm IDC Box | BOOMELE | LCSC | C11214 | 0.085
10 | 2.2kΩ | R0,R1,R2,R3 | R0603 | 4 | 0603WAF2201T5E | UniOhm | LCSC | C4190 | 0.001
11 | 1kΩ | R4 | R0603 | 1 | 0603WAF1001T5E | UniOhm | LCSC | C21190 | 0.001
12 | SS8050_C2150 | Q0,Q1,Q2,Q3 | SOT-23-3_L2.9-W1.3-P1.90-LS2.4-BR | 4 | SS8050 | CJ | LCSC | C2150 | 0.019

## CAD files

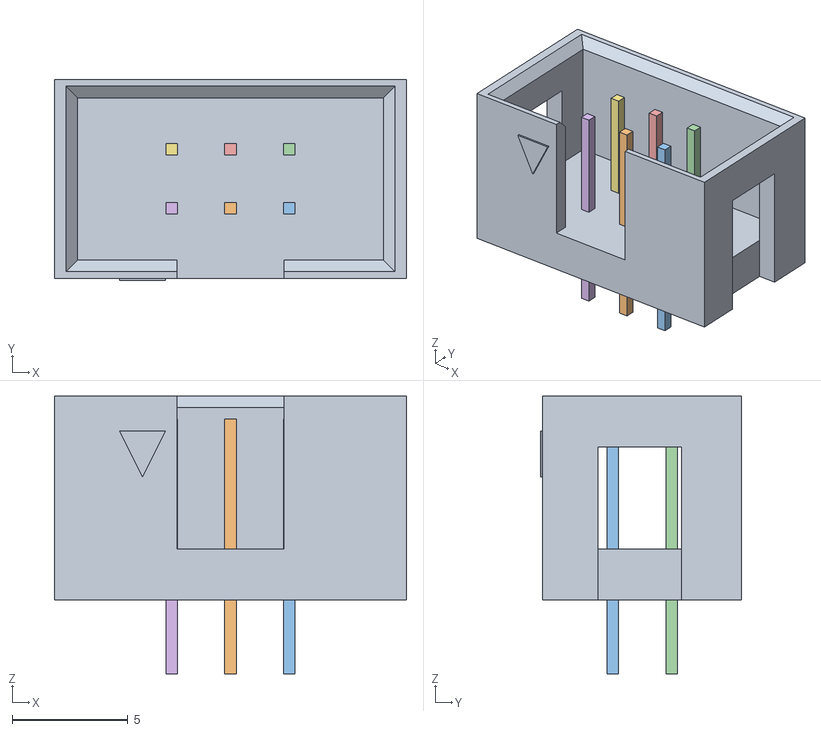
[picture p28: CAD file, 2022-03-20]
electronics2/IDC3dModel/IDC2x3.obj
15.2 x 8.70 x 12.0
pin
pin (1)
pin (2)
pin (3)
pin (4)
pin (5)

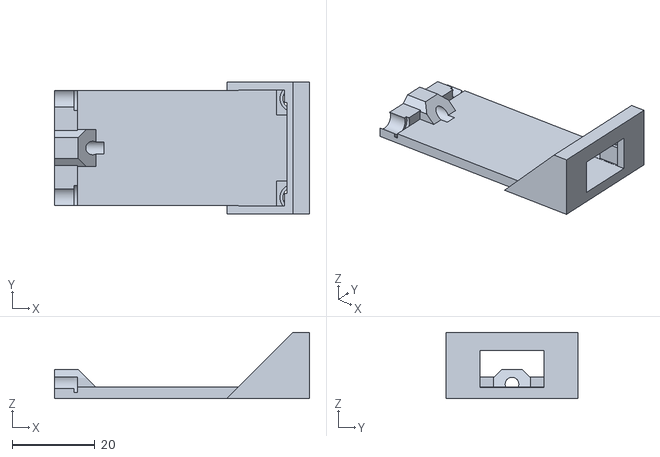
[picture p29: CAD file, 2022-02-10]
enclosure/case-bottom.stl
61.8 x 32.0 x 16.0

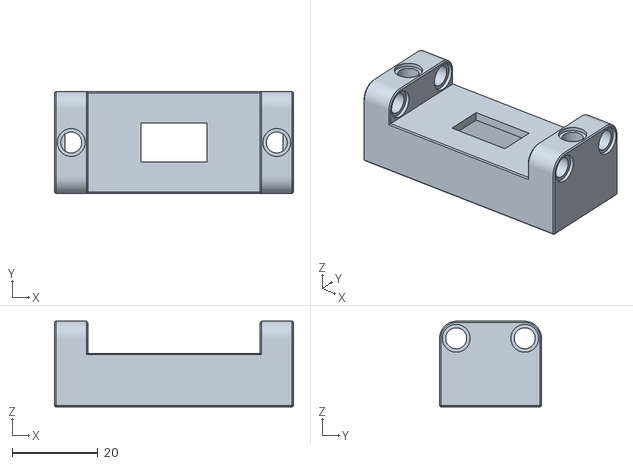
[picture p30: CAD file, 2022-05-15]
enclosure2/enclosure.stl
55.8 x 23.8 x 20.0

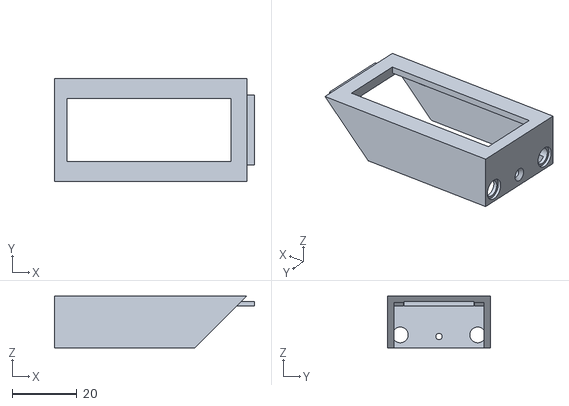
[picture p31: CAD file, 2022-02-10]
enclosure/case-top.stl
62.0 x 32.0 x 16.0

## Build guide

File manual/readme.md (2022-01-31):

# User manual for Seven Segment over Serial

This is the user manual of the "Seven Segment over Serial", also known by its short name **SSoS**.

[Introduction](#introduction)  
[Getting Started](#getting-started)  
[Examples](#examples)  
[Model](#model)  
[Control-characters](#control-characters)  
 . . . . [0x00 RESET](#0x00-reset)  
 . . . . [0x01 SET-FONT(id)](#0x01-set-fontid)  
 . . . . [0x02 SET-BRIGHTNESS(level)](#0x02-set-brightnesslevel)  
 . . . . [0x03 SET-BLINK-MASK(mask)](#0x03-set-blink-maskmask)  
 . . . . [0x04 SET-BLINK-TIMES(hi,lo)](#0x04-set-blink-timeshilo)  
 . . . . [0x05 SHOW-STRINGS(id0,id1)](#0x05-show-stringsid0id1)  
 . . . . [0x06 CURSOR-RIGHT](#0x06-cursor-right)  
 . . . . [0x07 (\a) BLINK-ENABLE](#0x07-a-blink-enable)  
 . . . . [0x08 (\b) CURSOR-LEFT](#0x08-b-cursor-left)  
 . . . . [0x09 (\t) CURSOR-EOLN](#0x09-t-cursor-eoln)  
 . . . . [0x0a (\n) LINE-COMMIT](#0x0a-n-line-commit)  
 . . . . [0x0b (\v) BLINK-DISABLE](#0x0b-v-blink-disable)  
 . . . . [0x0c (\f) CLEAR-AND-HOME](#0x0c-f-clear-and-home)  
 . . . . [0x0d (\r) CURSOR-HOME](#0x0d-r-cursor-home)  
 . . . . [0x0e DOT-DISABLE](#0x0e-dot-disable)  
 . . . . [0x0f DOT-ENABLE](#0x0f-dot-enable)  
 . . . . [0x10 CHAR-ENABLE](#0x10-char-enable)  
 . . . . [0x11 CHAR-DISABLE](#0x11-char-disable)  
 . . . . [0x12 CHAR-TIME(time)](#0x12-char-timetime)  
 . . . . [0x13 PATTERN-ONE(pat)](#0x13-pattern-onepat)  
 . . . . [0x14 PATTERN-ALL(p0,p1,p2,p3)](#0x14-pattern-allp0p1p2p3)  
 . . . . [0x1f RESET](#0x1f-reset)  
[Fonts](#fonts)  
[Strings](#strings)  

## Introduction

The Seven Segment over Serial device consists of 4 seven segment displays controlled by a micro-controller (an Arduino Nano).
Its key features are

 - Two built-in fonts: one for optimal readability and one where all characters have unique looks.
 - Support of brightness control and blinking.
 - Support for character mode (scrolling) and line mode (commit line at a time).
 - Control of cursor position (home, left, right, eoln).
 - Composing raw patterns on the 7-segment unit(s).
 - Dot replacement (how to render the dot in `2.7`) 
 - State monitoring (show internal state temporarily on the display).

## Getting started

Starting with SSoS is relatively easy. 
 - Hook it up the a host (3V3,GND) and connect host TX to SSoS RX
 - Configure UART on host as 8/N/115200.
 - If the host powers or resets the board, make sure to wait 2 sec before sending strings: SSoS needs 2 seconds to boot.
   The SSoS module first lests all LEDs  
   LED test  
   and then shows its name  
   name
 - Issue a write over serial: 
   ```python
   write("\f    Hello, world!    ")
   ```
 - This should clear the screen (`\f`) and scroll in "Hello, World!", and scroll that out (due to the four trailing spaces).
   The `W` will be a bit hard to read (and maybe also the `!`)

## Examples

Here are two examples of using SSoS via its USB port, connected to a PC, using Python to control SSoS.

Simple example:

```python
import serial
import time

ssos = serial.Serial('COM3',115200) # Resets board, so wait ~2sec
time.sleep(2)

ssos.write( b'\0HI')
```

HI

On a PC the (high) DTR line causes a reset; if we pull it low, the boot is faster

```python
import serial

ssos = serial.Serial(None,115200) # port=None, so not yet opened
ssos.dtr = False # Makes sure the board does not reset (would take 2 seconds)
ssos.port ='COM3' # Specify port
ssos.open() # Now open (fast)

ssos.write( b'\0HI')
```

## Model

The device has a notion of a **cursor**. By default the cursor has value 0, the position of the left-most 
7-segment unit. When sending a character to the device it is placed at the position of the cursor in 
the **frame buffer** and the cursor moves one position to the right.

If the cursor has value 4, the character can not be displayed (since the frame buffer only stores
the content for 7-segment units 0, 1, 2, and 3). Therefore, the text is **scrolled** left: the left-most 
character is dropped, and the right-most unit is freed. Then frame buffer location 3 is filled with 
the incoming character. The cursor remains at 4.

When a character is received by the device, its ASCII value if first converted to a 7-segment **pattern**
by looking it up in the current **font**. It is the _pattern_ that is stored in the frame buffer, not the _ASCII_ value.
So changing the font does not alter the screen content that is already present.
Two fonts are available: _LookAlike7s_ for optimal readability and _Unique7s_ where characters have unique looks. 
For example, `dD5S` shows as follows with _LookAlike7s_ on the left and _Unique7s_ on the right:

dD5S with LookAlike7s dD5S with Unique7s

Note that the fonts only support ASCII. The 7-segment pattern associated by a **high "ASCII"** value `128+i`, 
is the pattern associated with ASCII value `i` but with the (decimal) dot also switched on. Note that 
_none_ of the patterns below 128 have the (decimal) dot on, so this makes all character patterns unique (in _Unique7s_).

Also note that the fonts do not associate patterns with ASCII values below 32. 
Those characters are not displayable, instead those are **control characters** changing the state of the SSoS device. 
For example, the FF (Form Feed) character in ASCII (hex value 0C, decimal value 12, in C with `\f`) 
will clear the frame buffer and set the cursor to 0.
Other codes will change the font, brightness, blinking, dot replacement or (scrolling) mode. Some
of the control codes need to be followed by arguments (extra bytes), e.g. to pass the font ID.

The device can operate in two modes: character (default) and line. In **character mode**, each 
(displayable) character is immediately appended to the frame buffer and is thus visible. 
As noted above, if the cursor was at position 4, this causes a scroll. 
Scrolling is a nice feature for strings longer than 4, and this is where character mode is useful.
Just before every scroll step, the system actually pauses several tens of milliseconds (configurable as CHAR-TIME).
This results in a smooth scroll, assuming the host feeds characters faster than CHAR-TIME.

Downsides of character mode is speed (due to CHAR-TIME) and partial display updates. This is where line mode comes in.
In **line mode**, all (displayable) characters are appended to an internal line buffer.
The line buffer also has size 4, so if more characters are fed, it also scrolls, but without a delay and not visible.
The host needs to send a LINE-COMMIT (`\n`) to copy the line buffer to the frame buffer to make it visible.

The device has a limited reception buffer. Care should be taken not too send too many characters from the host.
This will overflow the internal reception buffer, causing **loss of received bytes**. 
This is more likely in character mode than in line mode due to the delays in scrolling.

The device is also capable of showing the **dot** (`.`) on a 7-segment unit of its own or using the dot-segment of the previous unit.
For example `2.7` can show as on the left (dot replacment enabled) or on the right (dot replacement disabled).

enabled disabled

## Control characters

The below table gives an overview of all control characters, the "SSoS commands"; details are in the subsections below.

Most subsections come with an example, the [source](examples/examples.py) is available in this repo.

The right-most column shows the defaults for all settings (in hex).

 | HEX | DEC | NAME | KEY |C-ESC | ASCII description               | SSoS command                                         |default (hex)|
 |:---:|:---:|:----:|:---:|:----:|:--------------------------------|:-----------------------------------------------------|------------:|
 |  00 |   0 |  NUL |  ^@ |  \0  | Null                            | [RESET](#0x00-reset)                                 |           - |
 |  01 |   1 |  SOH |  ^A |      | Start of Heading                | [SET-FONT(id)](#0x01-set-fontid)                     |          00 |  
 |  02 |   2 |  STX |  ^B |      | Start of Text                   | [SET-BRIGHTNESS(level)](#0x02-set-brightnesslevel)   |          04 |  
 |  03 |   3 |  ETX |  ^C |      | End of Text                     | [SET-BLINK-MASK(mask)](#0x03-set-blink-maskmask)     |          0F |  
 |  04 |   4 |  EOT |  ^D |      | End of Transmission             | [SET-BLINK-TIMES(hi,lo)](#0x04-set-blink-timeshilo)  |19,19 (×20ms)|  
 |  05 |   5 |  ENQ |  ^E |      | Enquiry                         | [SHOW-STRINGS(id0,id1)](#0x05-show-stringsid0id1)    |           - |  
 |  06 |   6 |  ACK |  ^F |      | Acknowledgment                  | [CURSOR-RIGHT](#0x06-cursor-right)                   |           - |  
 |  07 |   7 |  BEL |  ^G | `\a` | Bell (beep or the flash)        | [BLINK-ENABLE](#0x07-a-blink-enable)                 |          no |  
 |  08 |   8 |  BS  |  ^H | `\b` | Backspace                       | [CURSOR-LEFT](#0x08-b-cursor-left)                   |           - |  
 |  09 |   9 |  HT  |  ^I | `\t` | Horizontal Tab                  | [CURSOR-EOLN](#0x09-t-cursor-eoln)                   |           - |  
 |  0A |  10 |  LF  |  ^J | `\n` | Line Feed (moves line down)     | [LINE-COMMIT](#0x0a-n-line-commit)                   |           - |  
 |  0B |  11 |  VT  |  ^K | `\v` | Vertical Tab                    | [BLINK-DISABLE](#0x0b-v-blink-disable)               |         yes |  
 |  0C |  12 |  FF  |  ^L | `\f` | Form Feed (clear the screen)    | [CLEAR-AND-HOME](#0x0c-f-clear-and-home)             |         yes |  
 |  0D |  13 |  CR  |  ^M | `\r` | Carriage Return (start of line) | [CURSOR-HOME](#0x0d-r-cursor-home)                   |           - |  
 |  0E |  14 |  SO  |  ^N |      | Shift Out                       | [DOT-DISABLE](#0x0e-dot-disable)                     |          no |  
 |  0F |  15 |  SI  |  ^O |      | Shift In                        | [DOT-ENABLE](#0x0f-dot-enable)                       |         yes |  
 |  10 |  16 |  DLE |  ^P |      | Data Link Escape                | [CHAR-ENABLE](#0x10-char-enable)                     |         yes |  
 |  11 |  17 |  DC1 |  ^Q |      | Device Control 1 (often XON)    | [CHAR-DISABLE](#0x11-char-disable)                   |          no |  
 |  12 |  18 |  DC2 |  ^R |      | Device Control 2                | [CHAR-TIME(time)](#0x12-char-timetime)               |   19 (×20ms)|  
 |  13 |  19 |  DC3 |  ^S |      | Device Control 3 (often XOFF)   | [PATTERN-ONE(pat)](#0x13-pattern-onepat)             |           - |  
 |  14 |  20 |  DC4 |  ^T |      | Device Control 4                | [PATTERN-ALL(p0,p1,p2,p3)](#0x14-pattern-allp0p1p2p3)|           - |  
 |  1F |  31 |  US  |  ^_ |      | Unit Separator                  | [RESET](#0x1f-reset)                                 |           - |

### 0x00 RESET
The control character RESET will reset all settings to their default.
This includes clear screen and cursor home.

The table at the start of this section (last column) shows the defaults RESET effectuates.

Note that on power-up, the device performs a reset
but also prints its name (SSoS). 
So a CLEAR-AND-HOME (or a RESET) as a first command makes sense.

The command [0x1F](#0x1f-reset) is identical to command 0x00, it is added to support hosts that 
are not able to send a zero-byte 0x00 (a C `printf` might suffer from this).

#### Example

```python
  ssos.write( b'\0HI')
  time.sleep(1)
  ssos.write( b'\08.8.8.8.')
  time.sleep(1)
  ssos.write( b'\00075')
  time.sleep(1)
  ssos.write( b'\x0075')
  time.sleep(1)
  ssos.write( b'\0.75')
  time.sleep(1)
```

HI test \00075 \x0075 \0.75

`\0HI` resets (clears screen, homes cursor) and prints `HI`.

The second command `b'\08.8.8.8.'` is a LED test: it switches on all 8 LEDs in all 4 units.

When using the escape sequence `\0` to reset, make sure not to append digits:
`\075` does not reset and print `75`, it sends the octal character 075 (decimal 61) or `=`.
In this case, use `\00075` (the `\000` is the RESET command in octal), or use hex (`\x0075`),
or, a bit of a hack, write `\0.75` (SSoS will not print the `.` when there is no character before it).

### 0x01 SET-FONT(id)
The control character SET-FONT sets the font used for new incoming characters.

The font is selected with the argument, the font **id**.
The device supports two fonts: 0 selects _LookAlike7s_ and 1 _Unique7s_.
Font _LookAlike7s_ is optimized for readability and _Unique7s_ guarantees that each character has a unique look (pattern on the 7-segment display).
See the section on [Fonts](#fonts) for details.

Note that the argument byte is taken "mod 2" so `\x00`, `0`, `L`, or `l` all select _LookAlike7s_, and `\x01`, `1`, `U`, or `u` all select _Unique7s_.

The default value is 0 or _LookAlike7s_.

#### Example
```python
  ssos.write( b'\0dD5S')
  time.sleep(1)
  ssos.write( b'\0\1udD5S')
  time.sleep(1)
  ssos.write( b'\0S\x01US\x01LS')
  time.sleep(1)
```

dD5S default (LookAlike7s) dD5S Unique7s Both

 - First example: after reset we have a readable font (LookAlike7s). We can clearly read the `d`, `D`, `5` and `S`, but not tell them apart.
 - Second example: `\1u` uses octal for command 1 and `u` as argument. All characters are now different, but `D` and `S` are harder to read.
 - Third example: `\x01U` uses hex for command 1 and `U` respectively `L` as argument.
   Note that the fonts are used while "writing"; 
   changing the font afterwards does not change the looks of characters already written:
   the Unique7S `S` stays.

### 0x02 SET-BRIGHTNESS(level)
The control character SET-BRIGHTNESS sets the brightness of the 7-segment units.

The SSoS device deploys a form of PWM (very fast flashing) to implement brightness.
Every 7-segment unit is processed 5 ms so one frame takes 4units×5ms or 20 ms.
During this 5ms, each unit is switched on 1, 2, 3, 4 or 5 ms, and this determines the brightness.

The **level** is set with the argument, ranging from dark (1) up to and including bright (5).
Note that the argument byte is taken "mod 16" so `\x01` has the same result as `1`, `A`, or `a`, and `\x05` has the same result as `5`, `E` or `e`.
Values lower than 1 are clipped to 1, values higher than 5 clipped to 5.

The default value is 0x04 or 4/5 or 80%.

#### Example

```python
  ssos.write( b'\0l=df')
  time.sleep(1)
  ssos.write( b'\0\x025l=5')
  time.sleep(1)
  ssos.write( b'\0\x024l=4')
  time.sleep(1)
  ssos.write( b'\0\x023l=3')
  time.sleep(1)
  ssos.write( b'\0\x023l=2')
  time.sleep(1)
  ssos.write( b'\0\x021l=1')
  time.sleep(1)
```

l=df l=5 l=4 l=3 l=2 l=1

As argument we pass a digit (eg `4`) instead of the byte (`\x04`). Both work.

### 0x03 SET-BLINK-MASK(mask)
The control character SET-BLINK-MASK determines _which_ units blink when blinking is enabled.

For a display unit to blink the following settings need to be considered:
 - a mask determining which units blink, instead of being always on ([SET-BLINK-MASK](#0x03-set-blink-maskmask));
 - the blinking hi and lo times ([SET-BLINK-TIMES](#0x04-set-blink-timeshilo));
 - global blink enable ([BLINK-ENABLE](#0x07-a-blink-enable)/[BLINK-DISABLE](#0x0b-v-blink-disable)).

The **mask** is set with the argument, only the lower 4 bits are considered.
When bit `i` from the mask is 1, unit `i` will blink - if blinking is globally enabled.
When the bit is 0, unit `i` is (always) on.

The default value is 0x0F or 15 or 0b1111 or all units blink.

#### Example

```python
  ssos.write( b'\0ABCD')
  time.sleep(3)
  ssos.write( b'\a')
  time.sleep(3)
  ssos.write( b'\x03\x06')
  time.sleep(3)
  ssos.write( b'\x03\x09')
  time.sleep(3)
  ssos.write( b'\v')
  time.sleep(3)
```

After reset blink enable blink middle blink sides blink disable

- After reset, the display is not blinking.
- The default blink mask is 0b1111 (all units) and the default blink time is one second.
  After `\a` (or `\x07`) all units start to blink 500ms on, 500ms off.
- Mask 0x06 or 0b0110 is applied, so only middle two units blink.
- Mask 0x09 or 0b1001 is applied, so only side units blink.
- Command `\v` (or `\0x0b`) disables blinking.

### 0x04 SET-BLINK-TIMES(hi,lo)
The control character SET-BLINK-TIMES determines the hi time (unit on) and lo time (unit off) when blinking is enabled  (in 20ms increments).

See [SET-BLINK-MASK](#0x03-set-blink-maskmask) for all blinking settings to be considered.

This control character requires two arguments **hi** and **lo**.
The *hi* argument determines the unit on-time (in 20ms steps).
The *lo* argument determines the unit off-time (in 20ms steps).
Both arguments must be positive (not zero), and together they should be below 256 (or clipping will happen).

The default values are 0x19 and 0x19, or 25 and 25 or 500 ms and 500 ms (25×20ms).

#### Example

```python
  ssos.write( b'\0\aABCD')
  time.sleep(3)
  ssos.write( b'\x04\x0A\x0A')
  time.sleep(3)
  ssos.write( b'\x04\x14\x05')
  time.sleep(3)
  ssos.write( b'\x04\x05\x14')
  time.sleep(3)
```

- The `ABCD` are shown blinking 500ms on, 500ms off (1Hz).
  This is after reset, so mask is 0b1111 (all digits).
- Next, the frequency is turned up to 200ms on and 200ms off (10×20ms), so 2.5Hz.
- We keep the 2.5Hz but at a different duty cycle: 400ms on and 100ms off.
- In the final step that is reversed 100ms on and 400ms off.

### 0x05 SHOW-STRINGS(id0,id1)
SHOW-STRINGS is a development/debug feature, not typically used in normal operation.

The SSoS device has a list of internal settings, some static (application firmware version) some dynamic (current font). 
Each _setting_ consists of a _name_ and a _value_ (e.g. name `APP` and value `5.5`).
The names and values are referred to as "strings", and all strings have an (integer) id.
The names have an _even_ numbered id (starting at 0) and the associated value the _odd_ id immediatly following it.
Setting number `n` has thus two id's `2n` for its name and `2n+1` for its value.

The SHOW-STRINGS can show a series of strings by passing the start and end id.
There are 21 settings, so an id ranges from 0 to 41.

This command requires two arguments **id0** and **id1**.
The control character SHOW-STRINGS will momentarily (2 sec per string) show the strings from index **id0** up to (and including) index **id1**.
The upper limit is clipped to the highest id.
See below for a list of [Strings](#strings) (string id's).

Note `0x05 0x00 0xFF` will show all strings - since the `0xFF` will be clipped the the maximum.

This command will not change the state, cursor position and frame buffer are left unmodified once the command ends.

#### Example

```python
  ssos.write( b'\0-8\x05\x18\x23')
```

- The example resets SSoS and puts `-8` on the screen.
  Note that unit 0 has `-` or pattern 0b0100_000 or 0x40 and unit 1 has pattern 0b0111_111 or 0x7F.
  Note also that the cursor is at unit 2. The two remaining units are empty, i.e. have pattern 0x00.
- The example asks for showing strings 0x18 to 0x23.
  We get for 2 second the string 0x18; the abbreviated _name_ of "Content of display unit (frame buf) 0"  
  dsp.0
- Next we get for 2 second the string 0x19; the _value_ of "Content of display unit (frame buf) 0"  
  dsp.0
- We get the following strings on the device, each for two seconds.
  ```text
  DSP.0 0x40
  DSP.1 0x7F
  DSP.2 0x00
  DSP.3 0x00
  FONT  0x00
  CUR   0x02
  ```
- Note that display unit 0 has indeed 0x40, unit 1 has 0x7F and units 2 and 3 are blank (0x00).
- Note that the cursor is 2.
- When SHOW-STRINGS stops, the display is again `-8`.

If you run this with a USB cable, the SSoS device sends all strings over UART to the host
```text
Seven Segment over Serial (SSoS) version 5.5
Strings
 0x00 APP 5.5
 0x02 IDE 1.8.13
 0x04 CC 7.3.0
 0x06 YEAR 2022
 0x08 Mnth Jan
 0x0A DAY 30
 0x0C TIME 17.26
 0x0E BRIT 0x04
 0x10 BL.en 0x00
 0x12 BL.hi 0x19
 0x14 BL.lo 0x19
 0x16 BL.mk 0x0F
 0x18 DSP.0 0x6D
 0x1A DSP.1 0x6D
 0x1C DSP.2 0x5C
 0x1E DSP.3 0x6D
 0x20 FONT 0x00
 0x22 CUR 0x00
 0x24 DOT 0x01
 0x26 CH.en 0x01
 0x28 CH.tm 0x19
```

### 0x06 CURSOR-RIGHT
The control character CURSOR-RIGHT moves the cursor one position to the right
(if not already at the right-most position 4).

See also [CURSOR-LEFT](#0x08-b-cursor-left), [CURSOR-EOLN](#0x09-t-cursor-eoln), and [CURSOR-HOME](#0x0d-r-cursor-home).

#### Example

```python
  ssos.write( b'\0')
  time.sleep(1)
  ssos.write( b'\x06A')
  time.sleep(1)
  ssos.write( b'\x06B')
  time.sleep(1)
```

Blank cursor right A cursor right B

### 0x07 (`\a`) BLINK-ENABLE
The control character BLINK-ENABLE globally enables blinking (see also [BLINK-DISABLE](#0x0b-v-blink-disable)).

See [SET-BLINK-MASK](#0x03-set-blink-maskmask) for all blinking settings to be considered.

By default global blinking is disabled.

#### Example

See [SET-BLINK-MASK](#0x03-set-blink-maskmask).

### 0x08 (`\b`) CURSOR-LEFT
The control character CURSOR-LEFT moves the cursor one position to the left
(if not already at the left-most position 0).

See also [CURSOR-RIGHT](#0x06-cursor-right), [CURSOR-EOLN](#0x09-t-cursor-eoln), and [CURSOR-HOME](#0x0d-r-cursor-home).

#### Example

```python
  ssos.write( b'\0n=3')
  time.sleep(1)
  ssos.write( b'\b2')
  time.sleep(1)
  ssos.write( b'\b1')
  time.sleep(1)
  ssos.write( b'\x08 ')
  time.sleep(1)
```

n=3 n=2 n=1 n=

- After writing `n=3` the cursor backups and overwrites 3 with 2.
- We use `\b` (backspace) as alternative for `\x08` (in the last command).
- In the last command, the 1 is overwritten by a space.

### 0x09 (`\t`) CURSOR-EOLN
The control character CURSOR-EOLN moves the cursor to the right-most position (position 4).
This is convenient for printing right aligned (e.g. numbers).

See also [CURSOR-LEFT](#0x08-b-cursor-left), [CURSOR-RIGHT](#0x06-cursor-right), and [CURSOR-HOME](#0x0d-r-cursor-home).

#### Example

```python
  ssos.write( b'\0\t3.14')
  time.sleep(3)
  ssos.write( b'\0\x11\t2.7\n') # line mode
  time.sleep(1)
```

 

- The `t` or `0x09` puts the cursor at position 4. The next characters `3.14` scroll in from the right.
  The end result is a right-aligned number.
- The scrolling is slow, so you might consider switching to line-mode, disabling character mode (`0x11`).
  This does require to commit the line (`\n` or `0x0A`).

### 0x0A (`\n`) LINE-COMMIT
The control character LINE-COMMIT is ignored in character mode ([CHAR-ENABLE](#0x10-char-enable)).
When line mode is enabled ([CHAR-DISABLE](#0x11-char-disable)), an explicit LINE-COMMIT must be given to show the line.
See [Model](#model) section for detailed explanation.

By default character mode is enabled.

#### Example

```python
  ssos.write( b'\0character\n')
  time.sleep(6)
  ssos.write( b' mode')
  time.sleep(2)
  ssos.write( b'\x11')
  time.sleep(1)
  ssos.write( b'now line\n')
  time.sleep(1)
  ssos.write( b'yes')
  time.sleep(3)
  ssos.write( b'\n')
```

character mode line line yes

- After reset, the SSoS device is in character mode.
- `character` slowly scrolls in from right to left, the screen shows `cter` at the end.
- The `\n` from the previous command is ignored, so the second text (` mode`) scrolls the `cter` to the left.
- Switch to line mode `\x11` does nothing to the display.
- `line` appears instantaneously: no scrolling (so the `now ` part is not seen).
- The `yes` does not appear at first, there is no `\n` to commit that line.
- Three seconds later the `yes` line is committed. Note that a `\n` also clears the rest of the line on the display, 
  so there is a blank after the `s` of `yes`.
- As a general rule: in character mode _start_ each write with `\f` and in line mode _end_ each write with `\n`.

### 0x0B (`\v`) BLINK-DISABLE
The control character BLINK-DISABLE globally disables blinking (see also [BLINK-ENABLE](#0x07-a-blink-enable)).

See [SET-BLINK-MASK](#0x03-set-blink-maskmask) for all blinking settings to be considered.

By default global blinking is disabled.

#### Example

See [SET-BLINK-MASK](#0x03-set-blink-maskmask).

### 0x0C (`\f`) CLEAR-AND-HOME
The control character CLEAR-AND-HOME clears the screen (i.e. the frame/line buffer) and homes the cursor.
See also the command [CURSOR-HOME](#0x0d-r-cursor-home), it only homes.

#### Example

```python
  ssos.write( b'\0a=1')
  time.sleep(3)
  ssos.write( b'b=2')
  time.sleep(3)
  ssos.write( b'\fc=3')
  time.sleep(3)
```

a=1 b=2 c=3

- The message `a=1` appears immediately on the screen.
  The mode after reset is character mode, but since the message is not longer than the screen (3 versus 4) there is no scrolling.
- The next write `b=2` scrolls out the `a=1`. This is not only slow, but also leave the `1` on the screen.
- The final write shows the use of CLEAR-AND-HOME (`\f` or `\0x0C`): 
  it clears the screen so `c=2` appears immediately on the screen, no scrolling, no left-overs.
- As a general rule: in character mode _start_ each write with `\f` and in line mode _end_ each write with `\n`.

### 0x0D (`\r`) CURSOR-HOME
The control character CURSOR-HOME homes the cursor, i.e. sets it to 0. 
It does not clear screen, like [CLEAR-AND-HOME](#0x0c-f-clear-and-home).

See also [CURSOR-RIGHT](#0x06-cursor-right), [CURSOR-LEFT](#0x08-b-cursor-left), and [CURSOR-EOLN](#0x09-t-cursor-eoln).

#### Example

```python
  ssos.write( b'\0 59')
  time.sleep(2)
  ssos.write( b'\r-')
  time.sleep(2)
```

a=1 b=2

- The leading space is replaced by a `-`.
- We use `\r` as shorthand for `0x0D`.

### 0x0E DOT-DISABLE
The control character DOT-DISABLE disables dot replacement (see also [DOT-ENABLE](#0x0f-dot-enable)).
All `.` characters will be rendered in their own 7-segment unit according to the font, see [Model](#model) section for details.

By default dot replacement is enabled.

#### Example

```python
  ssos.write( b'\0')
  time.sleep(2)
  ssos.write( b'\f2.7')
  time.sleep(2)
  ssos.write( b'\f.E.F.G.H.')
  time.sleep(2)
  ssos.write( b'\x0E')
  time.sleep(2)
  ssos.write( b'\f2.7')
  time.sleep(2)
  ssos.write( b'\f.E.F.G.H.')
  time.sleep(2)
  ssos.write( b'\x0F')
  time.sleep(2)
  ssos.write( b'\f2.7')
  time.sleep(2)
```

2.7 (dot enabled) .E.F.G.H. (dot enabled) 2.7 (dot disabled) .E.F.G.H. (dot disabled) 2.7 (dot enabled)

- After reset, dot replacement is enabled. 
- The dots in `2.7` and `.E.F.G.H.` get replaced (except the dot at the beginning of `.E.F.G.H.` - there is no previous character).
- Next, dot replacement is disabled with command `0x0E`.
- The dots in `2.7` and `.E.F.G.H.` are not replaced. This makes `2.7` three units long.
  It makes `.E.F.G.H.I.` nine units long, so that scrolls (after reset, character mode is active).
- The `0x0F` enables dot replacement again, so the final `2.7` comes out with the decimal point again.

### 0x0F DOT-ENABLE
The control character DOT-ENABLE enables dot replacement (see also [DOT-DISABLE](#0x0e-dot-disable)).
All `.` characters will be replaced by switching on the decimal point of the 7-segment unit, see [Model](#model) section for details.

By default dot replacement is enabled.

#### Example

See [DOT-DISABLE](#0x0e-dot-disable).

### 0x10 CHAR-ENABLE
The control character CHAR-ENABLE enables _character mode_ (as opposed to _line mode_, see [CHAR-DISABLE](#0x11-char-disable)). 
See [Model](#model) section for details, but the summary: in _character mode_ received characters scrolls the display.
When character mode is enabled, make sure the [CHAR-TIME](#0x12-char-timetime) is set as desired.

Note that the device throttles reception of characters, so care should be taken not too send too many characters from the host.
This will overflow the internal reception buffer, causing loss of received bytes.

By default character mode is enabled.

#### Example

```python
  ssos.write( b'\0\x10')
  ssos.write( b'\f12345678')
  time.sleep(5)
  ssos.write( b'\fABCDEFGH')
  time.sleep(5)
  ssos.write( b'IJKLMNOP\n')
  time.sleep(5)
  ssos.write( b'\f    abcdefghi    ')
  time.sleep(5)
```

 - After rest, character mode is enabled by default, so the `\x10` is superfluous.
 - In character mode, `\n`s are ignored. It is suggested to start each line with `\f` ([CLEAR-AND-HOME](#0x0c-f-clear-and-home)).
 - This is not done for `IJKLMNOP`, and we see that it restarts scrolling, for scrolling out `EFGH`.
 - The best scroll effect is achieved by prepending and appending four spaces (last example).

```python
  ssos.write( b'\0\x10')
  ssos.write( b"\f1234567890ABCDEFGHIJKLMNOPQRSTUVWXYZ(-{`='}-)abcdefghijklmnopqrstuvwxyz")
```

This example shows that scrolling is slow, so a fast feeding host overflows the SSoS reception buffer.
In my case, the last characters `'nopqrstuvwxyz"` are lost, 58 are received.

### 0x11 CHAR-DISABLE
The control character CHAR-DISABLE (disables _character mode_ and thus) enables _line mode_. See also [CHAR-ENABLE](#0x10-char-enable).
See [Model](#model) section for details, but the summary: in _line mode_ received characters are buffered in an internal line buffer and are copied to the display when `\n` is received.
When line mode is enabled, make sure to send a [LINE-COMMIT](#0x0a-n-line-commit) (`\n`) at the end of each line.

By default character mode is enabled.

#### Example

```python
  ssos.write( b'\0\x11')
  ssos.write( b'abcd') # no show (\n missing)
  time.sleep(2)
  ssos.write( b'efgh\n')
  time.sleep(2)
  ssos.write( b'12345678\n')
  time.sleep(2)
  ssos.write( b'ABCDEFGH\n')
  time.sleep(2)
```

 - After rest, character mode is enabled by default, so we switch to line mode `\x11`.
 - In line mode, `\n`s are mandatory, they commit the received line to the framebuffer.
 - The `'abcd'` is not committed, so first 2 seconds is blank screen.
 - Then the screen shows `efgh`, 2 seconds later `5678` (without scrolling), 2 seconds later `EFGH` (again no scroll).

```python
  ssos.write( b'\0\x11')
  ssos.write( b"\f1234567890ABCDEFGHIJKLMNOPQRSTUVWXYZ(-{`='}-)abcdefghijklmnopqrstuvwxyz1.2.3.4.5.6.7.8.9.0.A.B.C.D.E.F.G.H.I.J.K.L.M.N.O.P.Q.R.S.T.U.V.W.X.Y.Z.\n")
```

The above code does not overflow the reception buffer, so the SSoS device can keep up with the host (my PC).

No overflow

### 0x12 CHAR-TIME(time)
The control character CHAR-TIME sets the wait time per character scrolled in character mode (in 20ms increments).
See [CHAR-ENABLE](#0x10-char-enable).

The **time** is set with the argument, ranging from no delay (0) up to max delay (255×20ms).
The argument may be 0.

For a smooth scroll on an empty display (to be more precise, when the cursor is 0), 
it is advised to start the message with 4 spaces, because the scroll delay is only applied when there is a _scroll_ of a character, 
i.e. when a character is received and the cursor is 4.

The default value is 0x19, or 25, or 500 ms (25×20ms).

#### Example

```python
  ssos.write( b'\0    ABCDEFGH    ')
  time.sleep(4)
  ssos.write( b'\x12\x05\f    ABCDEFGH    ')
  time.sleep(4)
```

 - The default CHAR-TIME after reset is 0x19 or 25 or 500ms.
 - The first message string is 4 spaces plus 8 chars plus 4 spaces, so 12 scrolls so takes 6 seconds.
 - Next we set CHAR-TIME to 5 or 100ms (5×20ms), so the message takes 1200ms.

### 0x13 PATTERN-ONE(pat)                                                                                        
The control character PATTERN-ONE adds a raw pattern to the display at the current cursor position (instead of looking up a pattern from an ASCII value in the font).

The **pat** is passed with the argument, a bit mask indicating which segments to switch on. 
Traditionally, the segments are labeled A-G (and P for the decimal point) in a clockwise fashion.
The bits of **pat** map to those segments in order:

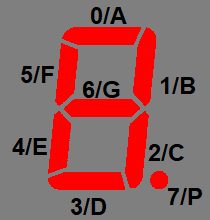
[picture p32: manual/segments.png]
segments


In other words, the character `1` typically switches on segments B and C, mapping to pattern 0b00000110, so the argument would be 0x06.

This command inserts a character in the flow, so it moves the cursor and optionally scrolls.

#### Example

```python
  ssos.write( b'\0A\x13\x49a')
  time.sleep(2)
```

A=a

 - The command 0x13 (PATTERN-ONE) gets as pattern 0x49 or 0b01001001, so segments 0/A, 3/D, and 6/G are on.
 - The PATTERN-ONE inserts this pattern into the flow (moving the cursor), unlike [PATTERN-ALL](#0x14-pattern-allp0p1p2p3).

### 0x14 PATTERN-ALL(p0,p1,p2,p3)                                                                                
The control character PATTERN-ALL adds a raw pattern to the complete display (all 4 units).

The **p0**, **p1**, **p2**, and **p3** are the raw patterns for units 0 to 3 respectively.

This command directly accesses the frame buffer; it does not use the cursor, nor the line buffer.

#### Example

```python
  ssos.write( b'\0A\x14\x21\x01\x08\x8C')
  time.sleep(2)
  ssos.write( b'B')
  time.sleep(2)
```

rectangle rectangle with b

 - After a reset an `A` is printed.
 - However, the PATTERN-ALL command overwrites the frame buffer, units 0-3, without looking at the cursor, unlike [PATTERN-ONE](#0x13-pattern-onepat).
 - The last pattern 0x8C or 0b10001100 switches on segments 2/C, 3/D and 7/P.
 - The command shows a partial rectangle.
 - After two seconds, a `B` is printed, the cursor was not changed by PATTERN-ALL, so it appears next to the overwritten `A`.

### 0x1F RESET

The command 0x1F is identical to command [0x00](#0x00-reset), it is added to support hosts that 
are not able to send a zero-byte 0x00 (a C `printf` might suffer from this).

#### Example

```python
  ssos.write( b'\x00HI')
  time.sleep(1)
  ssos.write( b'\x1f75')
  time.sleep(1)
```

HI \x0075

## Fonts

The active font can be selected with the command [SET-FONT](#0x01-set-fontid).

This is the font table for _Unique7s_ (not the default font):

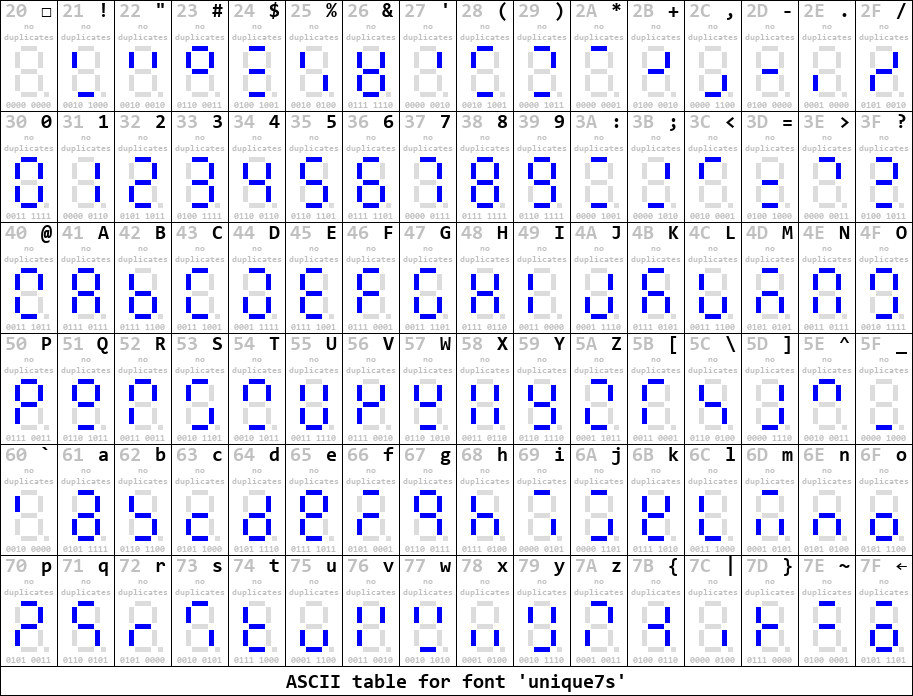
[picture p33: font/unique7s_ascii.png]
Unique7s


This is the font table for _LookAlike7s_ (the default font).
The cells with red marks have visual duplicates.

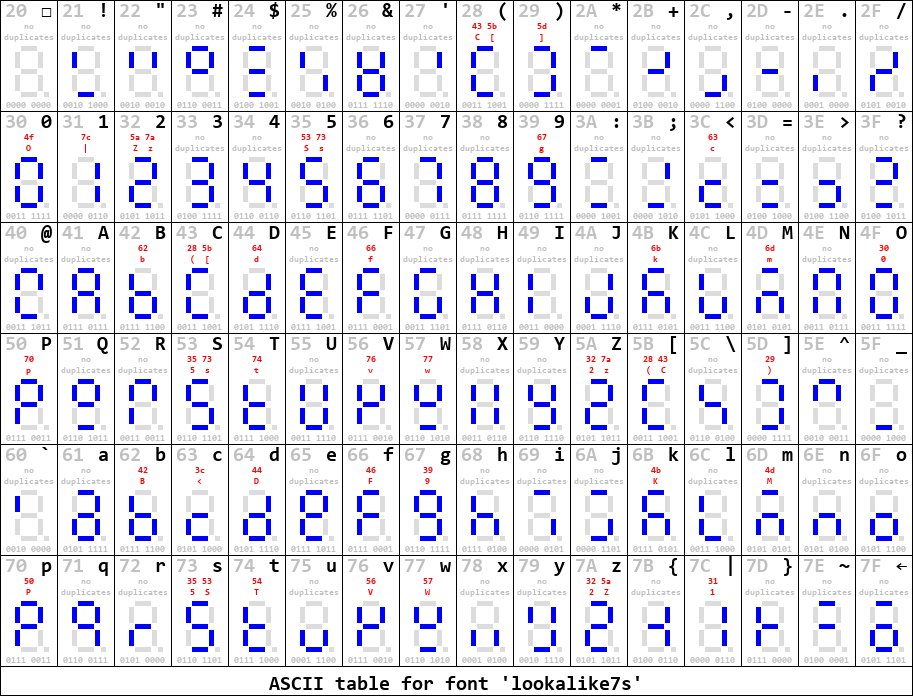
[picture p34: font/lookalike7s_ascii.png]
LookAlike7s


## Strings

The table below enumerates all strings that command [SHOW-STRINGS](#0x05-show-stringsid0id1) can show.
The odd entries are the setting _values_, the even entries just before them their _name_.

 |ID(hex)|ID(dec)| String                                            |
 |:-----:|:-----:|:--------------------------------------------------|
 |   00  |    0  | `APP`                                             |
 |   01  |    1  | SSoS app version e.g. `5.5`                       |
 |   02  |    2  | `IDE`                                             |
 |   03  |    3  | Arduino IDE version e.g. `1.8.13`                 |
 |   04  |    4  | `CC`                                              |
 |   05  |    5  | The C-compiler version, e.g. `7.3.0`              |
 |   06  |    6  | `YEAR`                                            |
 |   07  |    7  | Build time, year part e.g. `2022`                 |
 |   08  |    8  | `Mnth`                                            |
 |   09  |    9  | Build time-stamp, month part e.g. `Jan`           |
 |   0A  |   10  | `DAY`                                             |
 |   0B  |   11  | Build time-stamp, day part e.g. `30`              |
 |   0C  |   12  | `TIME`                                            |
 |   0D  |   13  | Build time-stamp, hour.min part e.g. `17.26`      |
 |   0E  |   14  | `BRIT`                                            |
 |   0F  |   15  | Brightness level, e.g. `0x04`                     |
 |   10  |   16  | `BL.en`                                           |
 |   11  |   17  | Blinking globally enabled, e.g. `0x00`            |
 |   12  |   18  | `BL.hi`                                           |
 |   13  |   19  | Blinking hi time, e.g. `0x19`                     |
 |   14  |   20  | `BL.lo`                                           |
 |   15  |   21  | Blinking lo time, e.g. `0x19`                     |
 |   16  |   22  | `BL.mk`                                           |
 |   17  |   23  | Blinking mask, e.g. `0x0F`                        |
 |   18  |   24  | `DSP.0`                                           |
 |   19  |   25  | Content of display unit (frame buf) 0, e.g. `0x6D`|
 |   1A  |   26  | `DSP.1`                                           |
 |   1B  |   27  | Content of display unit (frame buf) 1, e.g. `0x6D`|
 |   1C  |   28  | `DSP.2`                                           |
 |   1D  |   29  | Content of display unit (frame buf) 2, e.g. `0x5C`|
 |   1E  |   30  | `DSP.3`                                           |
 |   1F  |   31  | Content of display unit (frame buf) 3, e.g. `0x6D`|
 |   20  |   32  | `FONT`                                            |
 |   21  |   33  | Current font, e.g. `0x00`                         |
 |   22  |   34  | `CUR`                                             |
 |   23  |   35  | Current cursor position, e.g. `0x00`              |
 |   24  |   36  | `DOT`                                             |
 |   25  |   37  | Dot enabled, e.g. `0x01`                          |
 |   26  |   38  | `CH.en`                                           |
 |   27  |   39  | Character mode enabled, e.g. `0x01`               |
 |   28  |   40  | `CH.tm`                                           |
 |   29  |   41  | Character time, e.g. `0x19`                       |

(end)

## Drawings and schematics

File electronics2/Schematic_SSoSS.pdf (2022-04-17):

A | A

1

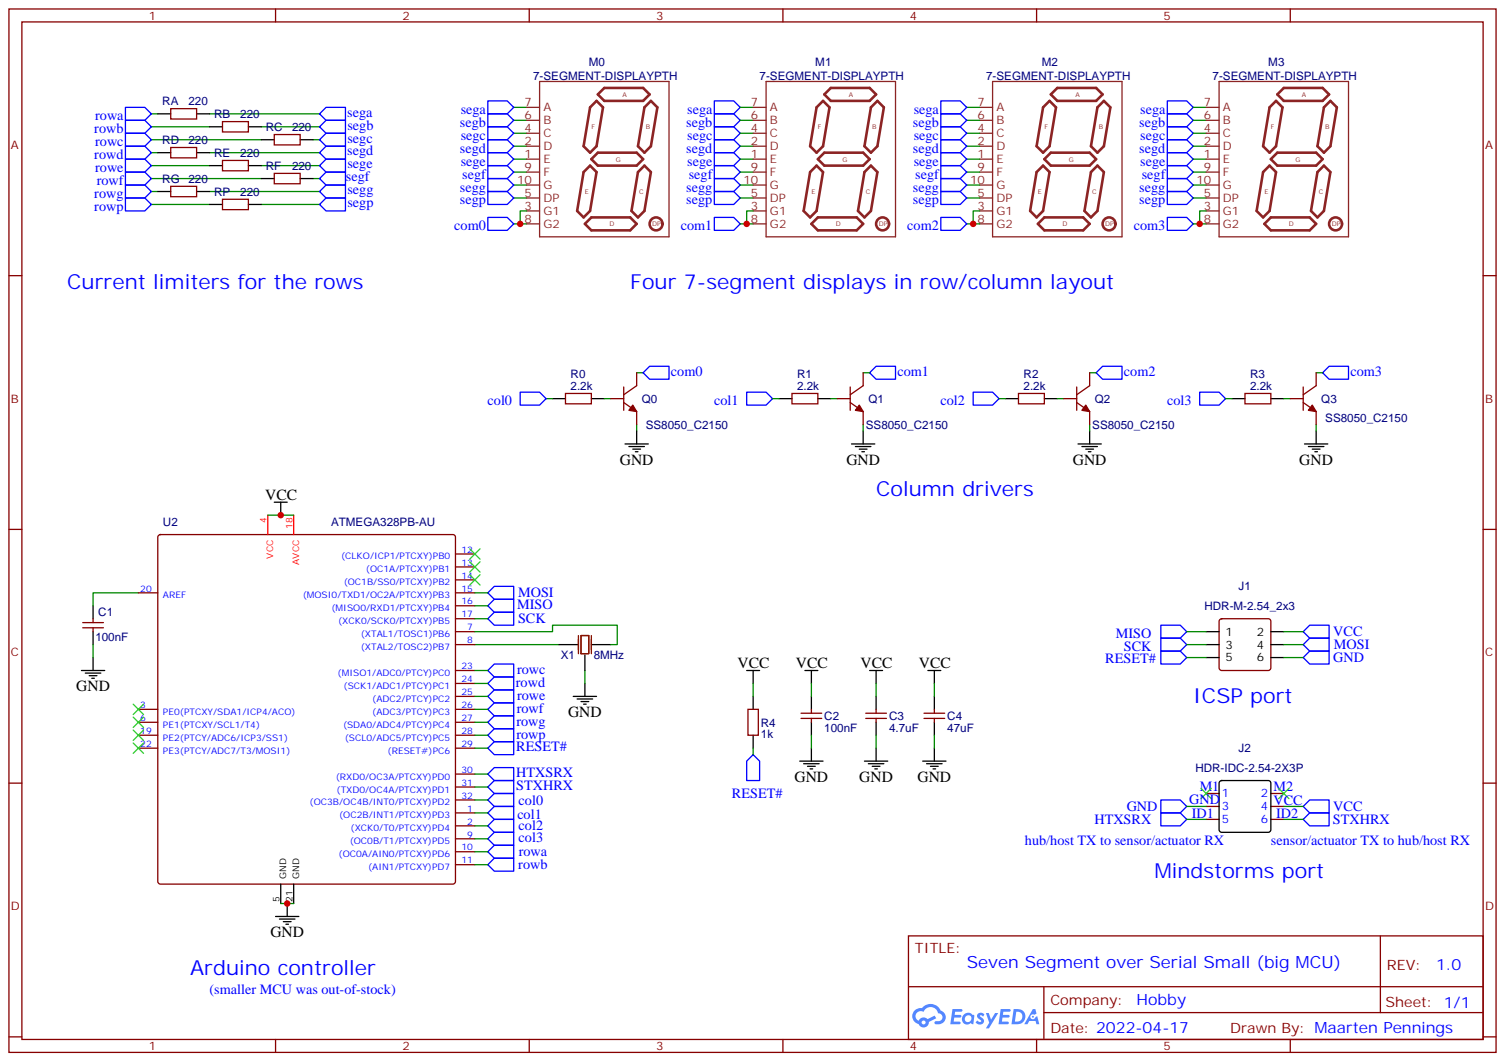
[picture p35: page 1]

Four 7-segment displays in row/column layout

Current limiters for the rows

hub/host TX to sensor/actuator RX

sensor/actuator TX to hub/host RX

Arduino controller
(smaller MCU was out-of-stock)

Drawn By: Maarten Pennings

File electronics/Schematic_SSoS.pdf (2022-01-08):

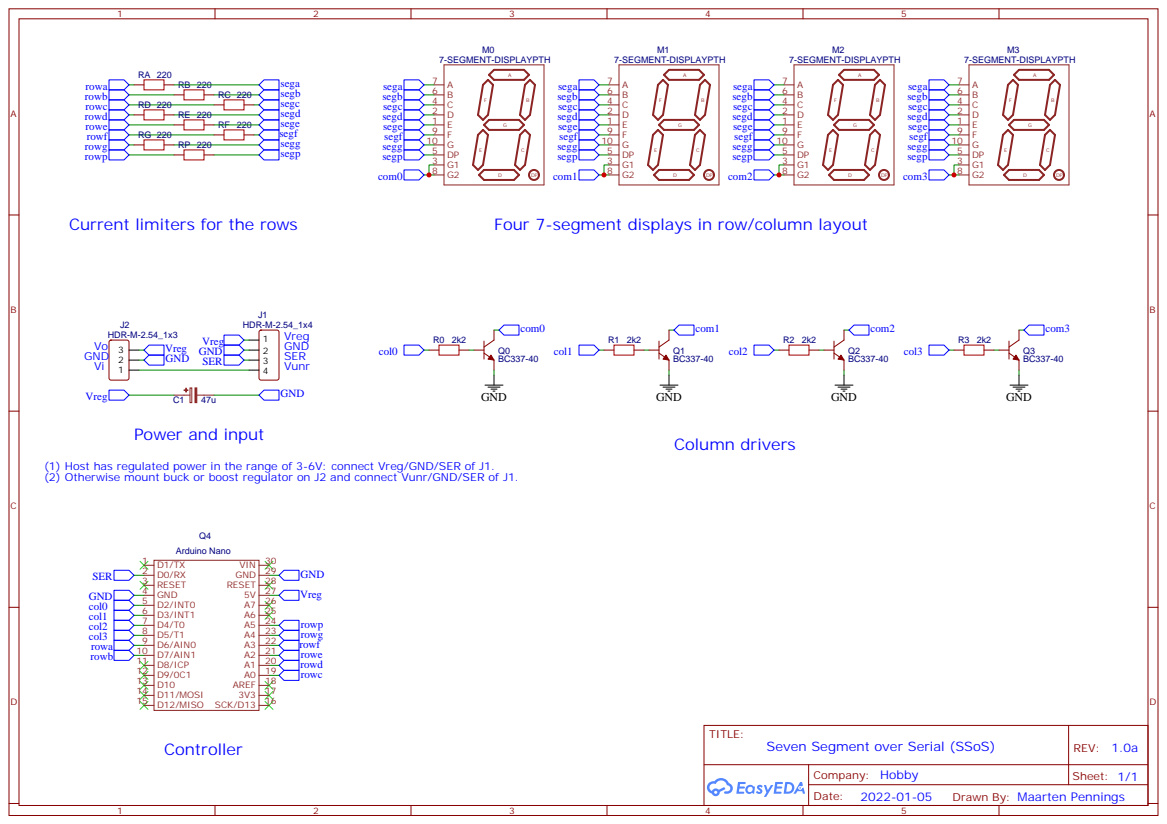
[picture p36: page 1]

(1) Host has regulated power in the range of 3-6V: connect Vreg/GND/SER of J1.
(2) Otherwise mount buck or boost regulator on J2 and connect Vunr/GND/SER of J1.

Drawn By: Maarten Pennings

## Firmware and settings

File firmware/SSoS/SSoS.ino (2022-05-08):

// SSoS.ino - Seven Segment over Serial firmware
// Suggested to build for Board "Arduino Pro or Pro Mini" with Processor "ATmega328P (3.3V, 8MHz)"
// This way, the drv7s knows the clock frequency and can adapt its refresh rate.
#define APP_LONGNAME "Seven Segment over Serial"
#define APP_NAME     "SSoS"
#define APP_VERSION  "5.6"
#define APP_WAIT_MS  2000


#include "drv7s.h"
#include "font.h"


////////////////////////////////////////////////////////////
// State maintained by the app
////////////////////////////////////////////////////////////


// State introduced by the app (driver also has some).
uint8_t app_fontid;
uint8_t app_cursor;
uint8_t app_dotenabled;
uint8_t app_charenabled;
uint8_t app_chartime20ms;


// Reset the complete state (driver and app).
void app_reset() {
  drv7s_reset(); // framebuf:0,0,0,0; brightness:4; blinking:disabled,25/25,0b0000
  app_fontid = FONT_LOOKALIKE7S; // FONT_UNIQUE7S;
  app_cursor = 0;
  app_dotenabled = 1;
  app_charenabled = 1;
  app_chartime20ms = 0x19; // 25*20=500ms
}


////////////////////////////////////////////////////////////
// Printing (updating display via driver)
////////////////////////////////////////////////////////////


// For char mode (if app_charenabled) function app_putpattern() puts to the real drv7s_framebuf[].
// For line mode (if not app_charenabled) function app_putpattern() puts to the app_linebuf[], 
// a \n is needed to commit (copy app_linebuf[] to drv7s_framebuf[]).
uint8_t app_linebuf[DRV7S_UNITCOUNT];


// This is the "print to 7-segment", filling the framebuffer exposed by drv7s, or the line buffer, depending on app_charenabled.
// `pattern`is a 8-bit code telling which LEDs of the 7-segment must be switched on (bit-0=segment-a, bit-1=segment-b, etc).
// The unit to update is identified by `app_cursor`. 
// If the cursor is beyond the last unit, the units are first shifted one position to the left ("scroll").
void app_putpattern(uint8_t pattern) {
  uint8_t * buf = app_charenabled ? drv7s_framebuf : app_linebuf;
  // Shift display if cursor is at end
  if( app_cursor>=DRV7S_UNITCOUNT ) {
    // In charmode, wait before the scroll
    if( app_charenabled ) delay(app_chartime20ms*20);
    // Scroll
    for( uint8_t i=1; i<DRV7S_UNITCOUNT; i++ ) buf[i-1] = buf[i];
    app_cursor = DRV7S_UNITCOUNT-1;
  } 
  // Determine pattern: lookup font
  // Write to driver
  buf[app_cursor] = pattern;
  // Advance cursor
  app_cursor++;
}


// Makes the dot or p-segment light up (of the character just before cursor).
void app_putdot( ) {
  if( app_cursor>0 ) {
    uint8_t * buf = app_charenabled ? drv7s_framebuf : app_linebuf;
    buf[app_cursor-1] |= 0x80;    
  }
}


// Used in line mode to copy the linebuffer to the framebuffer
void app_commit_line() {
  memcpy(drv7s_framebuf,app_linebuf,DRV7S_UNITCOUNT);
  memset(app_linebuf,0,DRV7S_UNITCOUNT);
  app_cursor = 0;
}


// Clears the screen and homes the cursor
void app_clear_home() {
  memset(drv7s_framebuf,0,DRV7S_UNITCOUNT); // clear 7-segments
  memset(app_linebuf,0,DRV7S_UNITCOUNT); // clear line buffer
  app_cursor = 0;
}


// Writes the string `chars` to the display, starting from position 0.
// Clips if longer than DRV7S_UNITCOUNT, pads with blanks if shorted than DRV7S_UNITCOUNT.
// Does have "dot enabled". Does not change `cursor`.
void app_putchars(const char *chars) {
  uint8_t i = 0;
  // If first char is a '.' it is printed as in the font (and not decimal point)
  while( i<DRV7S_UNITCOUNT && *chars!=0 ) {
    drv7s_framebuf[i] = font_get(app_fontid,*chars);
    chars++;
    if( *chars=='.' ) {
      drv7s_framebuf[i] |= 0x80;
      chars++;
    }
    i++;
  }
  while( i<DRV7S_UNITCOUNT ) {
    drv7s_framebuf[i] = 0;  
    i++;
  }
}


////////////////////////////////////////////////////////////
// Support SHOW-STRING
////////////////////////////////////////////////////////////


// Returns chars s[p1..p2), but any `dot` character is replaced by a dot. Truncates at DRV7S_UNITCOUNT.
// Appends \0. Uses global buffer, so one call at a time.
char app_string_buf[DRV7S_UNITCOUNT+2];
const char* app_slice(const char * s, uint8_t p1, uint8_t p2, char dot='\0' ) {
  uint8_t i=0;
  while( p1<p2 && i<DRV7S_UNITCOUNT+1 ) {
    uint8_t ch= s[p1++];
    if( ch==dot ) ch='.';
    app_string_buf[i++]= ch;
  }
  app_string_buf[i] = 0;
  return app_string_buf;
}


// Converts `val` to a string of the form 0xXX.
// Appends \0. Uses global buffer, so one call at a time.
const char* app_int(uint8_t val) {
  app_string_buf[0] = '0';
  app_string_buf[1] = 'x';
  uint8_t digit0 = val/16;
  app_string_buf[2] = (digit0<10?'0':'A'-10) + digit0;
  uint8_t digit1 = val%16;
  app_string_buf[3] = (digit1<10?'0':'A'-10) + digit1;
  app_string_buf[4] = '\0';
  return app_string_buf;
}


// String table usable to display all known strings (versions, driver state, app state).
uint8_t app_framebuf_backup[DRV7S_UNITCOUNT];
#define APP_STRING_ID_COUNT 42
const char* app_string(uint8_t id) {
  // App versions, compiler, date/time
  if( id== 0 ) return "APP";
  if( id== 1 ) return APP_VERSION;
  
  if( id== 2 ) return "IDE";
  #if ARDUINO!=10813 // I was lazy here
    #assert Next lined needs its returned string to be updated
  #endif
  if( id== 3 ) return "1.8.13";

  if( id== 4 ) return "CC";
  if( id== 5 ) return __VERSION__;
  
  if( id== 6 ) return "YEAR";
  if( id== 7 ) return app_slice(__DATE__,7,11);

  if( id== 8 ) return "Mnth";
  if( id== 9 ) return app_slice(__DATE__,0,3);
  
  if( id==10 ) return "DAY";
  if( id==11 ) return app_slice(__DATE__,4,6);
  
  if( id==12 ) return "TIME";
  if( id==13 ) return app_slice(__TIME__,0,6,':');
  
  // Driver state
  if( id==14 ) return "BRIT";
  if( id==15 ) return app_int( drv7s_brightness_get() );
  
  if( id==16 ) return "BL.en";
  if( id==17 ) return app_int( drv7s_blinking_mode_get() );

  if( id==18 ) return "BL.hi";
  if( id==19 ) return app_int( drv7s_blinking_hi_get() );

  if( id==20 ) return "BL.lo";
  if( id==21 ) return app_int( drv7s_blinking_lo_get() );

  if( id==22 ) return "BL.mk";
  if( id==23 ) return app_int( drv7s_blinking_mask_get() );

  if( id==24 ) return "DSP.0";
  if( id==25 ) return app_int( app_framebuf_backup[0] );
  
  if( id==26 ) return "DSP.1";
  if( id==27 ) return app_int( app_framebuf_backup[1] );

  if( id==28 ) return "DSP.2";
  if( id==29 ) return app_int( app_framebuf_backup[2] );

  if( id==30 ) return "DSP.3";
  if( id==31 ) return app_int( app_framebuf_backup[3] );

  // App state
  if( id==32 ) return "FONT";
  if( id==33 ) return app_int(app_fontid);
  
  if( id==34 ) return "CUR";
  if( id==35 ) return app_int(app_cursor);
  
  if( id==36 ) return "DOT";
  if( id==37 ) return app_int(app_dotenabled);

  if( id==38 ) return "CH.en";
  if( id==39 ) return app_int(app_charenabled);

  if( id==40 ) return "CH.tm";
  if( id==41 ) return app_int(app_chartime20ms);

  return " N.A.";
}

void app_show_strings(uint8_t id0, uint8_t id1) {
  // Clip
  if( id1>APP_STRING_ID_COUNT ) id1=APP_STRING_ID_COUNT-1;
  // Backup display
  memcpy(app_framebuf_backup,drv7s_framebuf,DRV7S_UNITCOUNT);
  // Dump all to serial  
  Serial.println("Strings"); 
  for( uint8_t i=0; i<APP_STRING_ID_COUNT; i+=2 ) {
    Serial.print(" "); Serial.print(app_int(i)); Serial.print(" "); Serial.print(app_string(i)); Serial.print(" "); Serial.println( app_string(i+1) );
  }
  // Show requested on display
  for( uint8_t id=id0; id<=id1; id++ ) { 
    app_putchars( app_string(id) ); delay(APP_WAIT_MS); 
  }
  // Restore framebuffer
  memcpy(drv7s_framebuf,app_framebuf_backup,DRV7S_UNITCOUNT);
}


////////////////////////////////////////////////////////////
// Handling characters that are commands (with arguments)
////////////////////////////////////////////////////////////


// Some chars below 0x20 are "commands" (eg BLINK-ENABLE).
// Some commands need one or more arguments (eg SET-FONT needs one more byte, the font id).
// The table below shows the length of each command plus arguments.
// A length of 0 indicates not-a-command, 1 indicates command-without-args, 2 indicates command-with-one byte arg, etc
// The table also shows the defaults (DFLT column), and actual ascii value in HEX/DEC/NAME/KEY and DESCRIPTION/
uint8_t app_cmd_len[0x20] = { 
//LEN     COMMAND                        DFLT HEX DEC NAME KEY ESC DESCRIPTION
    1, // RESET                                00   0  NUL  ^@  \0 Null
    2, // SET-FONT(0..1)                   01  01   1  SOH  ^A     Start of Heading
    2, // SET-BRIGHTNESS(1..5)             04  02   2  STX  ^B     Start of Text
    2, // SET-BLINK-MASK(0..F)             0F  03   3  ETX  ^C     End of Text
    3, // SET-BLINK-TIMES(0..FF,0..FF)  19,19  04   4  EOT  ^D     End of Transmission
    3, // SHOW-STRINGS(from,to)             -  05   5  ENQ  ^E     Enquiry
    1, // CURSOR-RIGHT                      -  06   6  ACK  ^F     Acknowledgment
    1, // BLINK-ENABLE                 see#0B  07   7  BEL  ^G  \a Bell (beep or the flash)
    1, // CURSOR-LEFT                       -  08   8  BS   ^H  \b Backspace
    1, // CURSOR-EOLN                       -  09   9  HT   ^I  \t Horizontal Tab
    1, // LINE-COMMIT                       -  0A  10  LF   ^J  \n Line Feed (moves line down)
    1, // BLINK-DISABLE                   yes  0B  11  VT   ^K  \v Vertical Tab
    1, // CLEAR-AND-HOME                  yes  0C  12  FF   ^L  \f Form Feed (clear the screen)
    1, // CURSOR-HOME                       -  0D  13  CR   ^M  \r Carriage Return (start of line)
    1, // DOT-DISABLE                  see#0F  0E  14  SO   ^N     Shift Out
    1, // DOT-ENABLE                      yes  0F  15  SI   ^O     Shift In
    1, // CHAR-ENABLE                     yes  10  16  DLE  ^P     Data Link Escape
    1, // CHAR-DISABLE                 see#10  11  17  DC1  ^Q     Device Control 1 (often XON)
    2, // CHAR-TIME                        19  12  18  DC2  ^R     Device Control 2
    2, // PATTERN-ONE(pat)                  -  13  19  DC3  ^S     Device Control 3 (often XOFF)
    5, // PATTERN-ALL(p0,p1,p2,p3)          -  14  20  DC4  ^T     Device Control 4
    0, // ignored                              15  21  NAK  ^U     Negative Acknowledgment
    0, // ignored                              16  22  SYN  ^V     Synchronous Idle
    0, // ignored                              17  23  ETB  ^W     End of Transmission Block
    0, // ignored                              18  24  CAN  ^X     Cancel
    0, // ignored                              19  25  EM   ^Y     End of Medium
    0, // ignored                              1A  26  SUB  ^Z     Substitute (windows: end-of-file)
    0, // ignored                              1B  27  ESC  ^[  \e Escape (start of sequence)
    0, // ignored                              1C  28  FS   ^\     File Separator
    0, // ignored                              1D  29  GS   ^]     Group Separator
    0, // ignored                              1E  30  RS   ^^     Record Separator
    1, // RESET (duplicate of 00)              1F  31  US   ^_     Unit Separator
};


// Actual command is in argv[0].
// Rest of arguments for that command (as specified in app_cmd_len[]) is available in rest of argv[].
// If app_cmd_len[ch]==0, this function will not be called with argv[0]==ch.
void app_cmd_exec(uint8_t * argv ) {
  uint8_t cmd = argv[0];
  if(        cmd==0x00 ) { // RESET (0x00/0)
    app_reset();
  } else if( cmd==0x01 ) { // SET-FONT (0x01/1 + font_id)
    app_fontid = argv[1] % 2;
  } else if( cmd==0x02 ) { // SET-BRIGHTNESS (0x02/2 + brightness_level)
    drv7s_brightness_set( argv[1]%16 ); // %16 allows \x01,1,A,a all act as brightness 1
  } else if( cmd==0x03 ) { // SET-BLINK-MASK (0x03/3 + blink_mask)
    drv7s_blinking_mask_set(argv[1]%16);
  } else if( cmd==0x04 ) { // SET-BLINK-TIMES (0x04/4 + hitime + lotime)
    drv7s_blinking_hilo_set(argv[1],argv[2]);
  } else if( cmd==0x05 ) { // SHOW-STRINGS (0x05/5 + from_index + to_index)
    app_show_strings(argv[1],argv[2]);
  } else if( cmd==0x06 ) { // CURSOR-RIGHT (0x06/6)
    if( app_cursor<DRV7S_UNITCOUNT ) app_cursor++;
  } else if( cmd==0x07 ) { // BLINK-ENABLE (0x07/7/\a)
    drv7s_blinking_mode_set(1);
  } else if( cmd==0x08 ) { // CURSOR-LEFT (0x08/8/\b)
    if( app_cursor>0 ) app_cursor--;
  } else if( cmd==0x09 ) { // CURSOR-EOLN (0x09/9/\t)
    app_cursor = DRV7S_UNITCOUNT;
  } else if( cmd==0x0A ) { // LINE-COMMIT (0x0A/10/\n)
    if( !app_charenabled ) app_commit_line();
  } else if( cmd==0x0B ) { // BLINK-DISABLE (0x0B/11/\v)
    drv7s_blinking_mode_set(0);
  } else if( cmd==0x0C ) { // CLEAR-AND-HOME (0x0C/12/\f)
    app_clear_home();
  } else if( cmd==0x0D ) { // CURSOR-HOME (0x0D/13/\r)
    app_cursor = 0; // cursor home
  } else if( cmd==0x0E ) { // DOT-DISABLE (0x0E/14)
    app_dotenabled = 0;
  } else if( cmd==0x0F ) { // DOT-ENABLE (0x0F/15)
    app_dotenabled = 1;
  } else if( cmd==0x10 ) { // CHAR-ENABLE (0x10/16)
    app_charenabled = 1;
  } else if( cmd==0x11 ) { // CHAR-DISABLE (0x11/17)
    app_charenabled = 0;
  } else if( cmd==0x12 ) { // CHAR-TIME (0x12/18 + char_time)
    app_chartime20ms = argv[1];
  } else if( cmd==0x13 ) { // PATTERN-ONE (0x13/19 + pattern)
    // Spec-point: inserts a "raw" character so moves cursor
    app_putpattern( argv[1] );  
  } else if( cmd==0x14 ) { // PATTERN-ALL (0x14/20 + pattern + pattern + pattern + pattern)
    // Spec-point: fills display but does not change cusror
    for( uint8_t i=0; i<DRV7S_UNITCOUNT; i++ ) drv7s_framebuf[i] = argv[i+1];
  } else if( cmd==0x1f ) { // RESET (0x1F/31)
    // Duplicate of 0x00 (in case the host can not send 0x00)
    app_reset();
  }
}


////////////////////////////////////////////////////////////
// App setup and loop
////////////////////////////////////////////////////////////


// Some incoming characters are actually a command, optionally with some arguments (extra characters).
#define APP_CMD_BUFSIZE  5 // Size for command buffer; biggest command (PATTERN-ALL) must fit.
#define APP_CMD_ARGC     (app_cmd_len[app_cmd_argv[0]]) // The number of bytes required for the command in app_cmd_argv[0].
uint8_t app_cmd_argv[APP_CMD_BUFSIZE]; // At index 0 the command, next its arguments. Note on startup this hold command 0 with len 0.
uint8_t app_cmd_argc;  // Number of bytes for app_cmd_argv[0] that are already collected


// Enable Serial for incoming characters.
// Enable 7-Segment driver (timer based interrupt service routine)
void setup() {
  // Setup serial
  Serial.begin(115200);
  Serial.println("\n\n" APP_LONGNAME " (" APP_NAME ") version " APP_VERSION);

  // Setup driver and app
  drv7s_setup();
  app_reset();

  // LED test and welcome banner
  app_putchars("8.8.8.8.");
  delay(500);
  app_putchars(APP_NAME);

  // No command pending
  app_cmd_argc = APP_CMD_ARGC;
}


// Process characters coming in from Serial. 
// Either send char to display with app_putpattern(), or treat it as a command app_cmd_exec().
void loop() {
  int ch= Serial.read();
  uint8_t ascii = ch & 0x7F;
  if( ch==-1 ) {
    // no char, skip
  } else if( app_cmd_argc < APP_CMD_ARGC ) { // command pending (collecting arguments)
    app_cmd_argv[app_cmd_argc] = ch;
    app_cmd_argc++;
    if( app_cmd_argc==APP_CMD_ARGC ) {
      app_cmd_exec(app_cmd_argv); // all arguments are collected for command, exec
    }
  } else if( ascii<0x20 ) { // incoming char is a (potentially) a command
    if( app_cmd_len[ascii]>0 ) {
      app_cmd_argv[0] = ascii;
      app_cmd_argc = 1;
      if( app_cmd_argc==APP_CMD_ARGC ) app_cmd_exec(app_cmd_argv); // command needs no arguments, exec now
    }
  } else if( ascii=='.' && app_dotenabled ) {
    app_putdot( );  
  } else {
    app_putpattern( font_get(app_fontid,ch) );  
  }
}

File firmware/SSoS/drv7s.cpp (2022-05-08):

// drv7s.cpp - the 7-segment driver

#include "Arduino.h"
#include "drv7s.h"

// Define the following macro to have the builtin LED (it is on D13 = PB5) pulse on every click tick
//#define DRV7S_DEBUG 1


// The frame buffer is exposed publicly
uint8_t drv7s_framebuf[DRV7S_UNITCOUNT]; // Desired content on the 7-segment units (each 1-bit is a segment that is on)

// Private part of 7-segment driver
static uint8_t drv7s_slot;       // current time subdivision of the control interval of a unit (for brightness control)
static uint8_t drv7s_unit;       // the 7-segment unit currently under control
static uint8_t drv7s_frame;      // the 7-segment unit currently under control
static uint8_t drv7s_brightness; // desired brightness level (1..DRV7S_SLOTCOUNT)
static uint8_t drv7s_alwayshi;   // desired blinking state (0 is blinking, 1 is always hi)
static uint8_t drv7s_framecount; // desired blinking period (in frames)
static uint8_t drv7s_frameshi;   // desired hi-time for blinking (in frames)
static uint8_t drv7s_noblinkmask;// desired bit mask indicating which units are exempt from blinking (are always on)

// Resets state (framebuf:0,0,0,0; brightness:4; blinking:disabled,25/25,0b0000)
void drv7s_reset() {
  memset(drv7s_framebuf,0,DRV7S_UNITCOUNT); // Wipe screen

  drv7s_slot       = DRV7S_SLOTCOUNT-1;     // First ISR will roll over to slot 0
  drv7s_unit       = DRV7S_UNITCOUNT-1;     // First ISR will roll over to unit 0  
  drv7s_frame      = drv7s_framecount-1;    // First ISR will roll over to frame 0  

  drv7s_brightness = 4;                     // Brightness to 4/5

  drv7s_alwayshi   = 1;                     // blinking disabled
  drv7s_framecount = 0x32;                  // 0x32*20 = 50*20 = 1000 ms (1 frame is 20ms)
  drv7s_frameshi   = 0x19;                  // 0x19*20 = 25*20 =  500 ms (1 frame is 20ms)
  drv7s_noblinkmask= 0;                     // all units blink
}

// Sets the brightness level to `val`, constraining to [1,DRV7S_SLOTCOUNT], default 4.
void drv7s_brightness_set( uint8_t val ) {
  drv7s_brightness = constrain(val,1,DRV7S_SLOTCOUNT);
}

// Returns current brightness level.
uint8_t drv7s_brightness_get(  ) {
  return drv7s_brightness;
}

// Sets the blinking mode to `enabled` (0 is disabled, otherwise enabled), default disabled.
void drv7s_blinking_mode_set( uint8_t enabled ) {
  drv7s_alwayshi = enabled==0; 
}

// Returns current blinking mode.
uint8_t drv7s_blinking_mode_get(  ) {
  return ! drv7s_alwayshi;
}

// Sets the blinking to `hi` frames "on", then `lo` frames "off", constraining each to [1,254] and lo such that hi+lo<256, default 0x19,0x19.
void drv7s_blinking_hilo_set( uint8_t hi, uint8_t lo ) {
  hi = constrain(hi,1,254); // min is 1 so there is some hi, max is 254 so there is room for lo
  lo = constrain(lo,1,254); // min is 1 so there is some lo, max is 254 so there is room for hi
  uint8_t sum = hi+lo; // prepare to check for overflow
  if( sum>hi ) drv7s_framecount=sum; else drv7s_framecount=255; 
  drv7s_frameshi = hi;
}

// Returns current blinking hi time (in frames).
uint8_t drv7s_blinking_hi_get(  ) {
  return drv7s_frameshi;
}

// Returns current blinking lo time (in frames).
uint8_t drv7s_blinking_lo_get(  ) {
  return drv7s_framecount - drv7s_frameshi;
}

// Sets the blinking mask: if bit i is set, unit i will blink. Only uses lower DRV7S_UNITCOUNT bits, default 0b1111 (all units blink).
void drv7s_blinking_mask_set( uint8_t mask ) {
  drv7s_noblinkmask = ~mask; 
}

// Returns current blinking mask.
uint8_t drv7s_blinking_mask_get(  ) {
  return (~ drv7s_noblinkmask ) & ((1<<DRV7S_UNITCOUNT)-1);
}

// How the ports are wired. Letter denotes segment, digit denotes common of unit, nc means not connected
//   bit     7  6  5  4  3  2  1  0
//   Port C: nc nc p  g  f  e  d  c
//   label : A7 A6 A5 A4 A3 A2 A1 A0
//   Port D: b  a  3  2  1  0  nc nc
//   label : D7 D6 D5 D4 D3 D2 Rx TX

// drv7s_isr() allocated to TIMER2_COMPA_vect
ISR( TIMER2_COMPA_vect ) {
  #if DRV7S_DEBUG
    // Debug: track ISR ticks using builtin LED (it is on D13 = PB5)
    PORTB |= 1<<5; // ON
    PORTB &= ~(1<<5); // OFF
  #endif
  // Timer tick: move to next slot
  drv7s_slot += 1;
  // If slot exceeds brightness level, switch current unit off 
  if( drv7s_slot >= drv7s_brightness ) {
    PORTD = 0; // all columns off (also switches off rows, but don't care)
  }
  // If slot wraps around, move to next unit
  if( drv7s_slot >= DRV7S_SLOTCOUNT ) {
    drv7s_slot = 0;
    drv7s_unit += 1;    
    // Wrap around the unit
    if( drv7s_unit >= DRV7S_UNITCOUNT ) {
      drv7s_unit = 0;
      drv7s_frame += 1;
      // Wrap around the frame
      if( drv7s_frame >= drv7s_framecount) {
        drv7s_frame = 0;
      }
    }
    // New unit under control, switch it on (unless in blinking off)
    if( drv7s_alwayshi || (drv7s_noblinkmask & (1<<drv7s_unit)) || (drv7s_frame < drv7s_frameshi)  ) {
      uint8_t rows = drv7s_framebuf[drv7s_unit];
      uint8_t col = 1 << drv7s_unit;
      PORTC = (rows>>2);
      PORTD = ((rows&3)<<6) | (col<<2); // colums on after rows
    }
  }
}

#if 0
#define XSTR(x) STR(x)
#define STR(x) #x
#pragma message "F_CPU = " XSTR(F_CPU)
#endif

// Setup (hardware registers) for 7-segments
void drv7s_setup() {
  // Setup row/column drivers
  PORTC = 0;   // all port C outputs low
  PORTD = 0;   // all port D outputs low
  DDRC = 0xFF; // all port C pins are output
  DDRD = 0xFF; // all port D pins are output

  #if DRV7S_DEBUG
    // Debug: track ISR ticks using builtin LED (it is on D13 = PB5)
    DDRB  = 1<<5; // pin PB5 as output
  #endif
  
  // Configure initial state
  drv7s_reset();
  
  // Setup timer 2 to calling IST every 1 ms
  noInterrupts(); // Disable all interrupts - cli()
  TCCR2A = 0; // Do not understand why, but without first setting to 0, we get 4.063us instead of 1ms
  // Set Output Compare Register A for 1kHz (1ms)
  OCR2A = F_CPU/*CPU*/  /  64/*prescaler*/  /  1000/*targetfreq*/  -  1;
  // Turn on CTC mode (Clear Timer on Compare Match) WGM2[210]=010 (so we only set WGM21)
  TCCR2A = 1 << WGM21;
  // Select prescaler of 64 with Clock Select CS2[210]=100 (so we only set CS22)
  TCCR2B = 1 << CS22;   
  // Enable timer compare interrupt
  TIMSK2 = 1 << OCIE2A;
  interrupts(); // Re-enable all interrupts - sei()
}
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

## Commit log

2022-01-05 adds PCB
2022-01-05 adds PCB (text)
2022-01-16 driver corrects "sets" instead of ignore
    [drv7s.cpp]
2022-01-29 Add examples to user manual mimic->lookalike reset to 0 fixed bug in showstring
    [SSoS.ino, examples.py]
2022-01-30 v5.5
    - char delay _before_ scroll
    - app_putchars handles dot at begin and end
    - extra RESET at 0x1f
    - fix bug (init app_cmd_arg)
    [SSoS.ino]
2022-01-31 PCB photos
2022-01-31 added images of actual PCB
2022-02-07 board design considerations
2022-02-10 adds enclosure
    [case-bottom.stl, case-top.stl]
2022-02-10 fix STL links
2022-03-20 Add SSoSS
    [BOM_PCB_SSoSS_2022-03-20.csv, IDC2x3.obj, PickAndPlace_PCB_SSoSS_2022-03-20.csv]
2022-04-17 SSoSS (big MCU)
    [BOM_PCB_SSoSS_2022-03-20.csv, BOM_SSoSS2-board_2022-04-17.csv, PickAndPlace_PCB_SSoSS_2022-03-20.csv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]
2022-05-07 holes, video, no boot
2022-05-08 more details on fuses
2022-05-08 Fix drv7s clock bug
    [SSoS.ino, drv7s.cpp]
2022-05-08 photos of assembled display
2022-05-15 adds enclosure 2
    [enclosure.stl]
2022-05-15 add enclosure link
2022-05-21 adds 3d print assessment
2022-05-22 adds Ultrasonic
